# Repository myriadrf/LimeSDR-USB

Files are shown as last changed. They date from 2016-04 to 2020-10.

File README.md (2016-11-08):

# LimeSDR

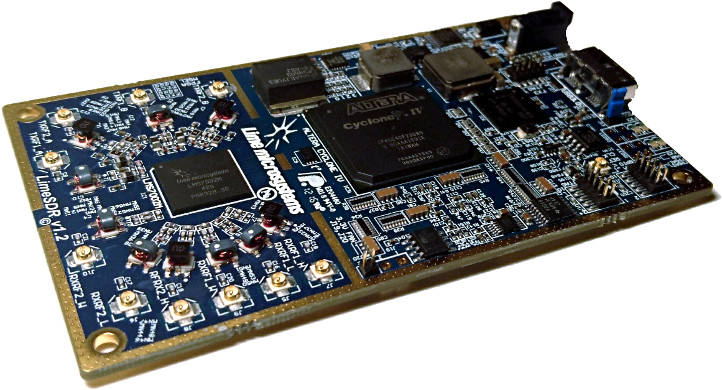
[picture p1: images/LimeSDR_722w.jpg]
LimeSDR board


The [LimeSDR](https://myriadrf.org/projects/limesdr/) board provides a hardware platform for developing and prototyping high-performance and logic-intensive digital and RF designs using Altera’s Cyclone IV FPGA and Lime Microsystems transceiver.

* **USB Interface** 
  * Cypress FX3 super speed USB 3rd generation controller 
* **FPGA Features**
  * Cyclone IV EP4CE40F23C8N device in 484-pin FPGA
  * 39’600 logic elements
  * 1134 Kbits embedded memory
  * 116 embedded 18x18 multipliers 
  * 4 PLLs 
* **FPGA Configuration**
  * JTAG mode configuration 
  * Active serial mode configuration 
  * Possibility to update FPGA gateware by using FX3 (USB)
* **Memory Devices** 
  * 2x 1Gbit (64M x 16) DDR2 SDRAM 
  * 4Mbit flash for FX3 firmware
  * 16Mbit flash for FPGA gateware
  * 3x 64K (8K x 8) EEPROMs for LMS MCU firmware, LMS MCU data and FX3 data
* **Connections**
  * 6-12V DC power jack
  * FPGA GPIO headers
  * Micro USB3.0 (type B) connector or USB3.0 (type A) plug
  * Coaxial RF (U.FL) connectors
* **Clock System**
  * 30.72MHz ±250 ppb on board VCTCXO
  * Possibility to lock VCTCXO to external clock or tune VCTCXO by onboard DAC 
  * Programmable clock generator for the FPGA reference clock input or LMS PLLs
* **Board Size** 60mm x 100mm (2.36” x 3.94”) 

## Contents

The directory structure is as follows:

      fx3/                       - Cypress FX3 USB 3.0 controller firmware
         
      gateware/                  - Altera Cyclone IV FPGA project

      hardware/<variant>/<version>/
          Libraries/             - Component Libraries
          OutputJobs/            - Output jobs
          PCB/                   - PCB design
          Project Outputs/       - BOM, rule check reports, Gerbers, pick & place files, PDFs
          Schematics/            - Schematic diagrams

### Revisions

The design databases published correspond to hardware revisions which have either gone into full production or been issued in limited number for testing in the community. 

Please note that only certain versions of FPGA firmware and FX3 firmware will work with a given hardware revision. For further details see the FPGA and FX3 projects.

## Associated projects

### FPGA gateware

The FPGA gateware sources are located in the [LimeSDR-USB_GW repository](https://github.com/myriadrf/LimeSDR-USB_GW).

### FX3 firmware

The Cypress FX3 USB 3.0 controller firmware sources are located in the [LimeSDR-USB_FX3 repository](https://github.com/myriadrf/LimeSDR-USB_FX3).

### Host driver

The host driver sources are located in the [LimeSuite repository](https://github.com/myriadrf/LimeSuite).

## Licensing

The hardware designs are licensed under a Creative Commons Attribution 3.0 Unported licence.

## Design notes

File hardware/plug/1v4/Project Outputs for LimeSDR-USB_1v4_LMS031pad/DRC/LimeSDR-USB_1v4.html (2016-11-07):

Altium

# Design Rule Verification Report

Date: | | 2016-09-13
Time: | | 16:37:09
Elapsed Time: | | 00:03:49
Filename: | | E:\Saniok\Lime Micro\Lime PCBs\LimeSDR-USB_1v4\Altium designer design files\PCB\LimeSDR-USB_1v4.PcbDoc

Warnings: | | 12
Rule Violations: | | 0

## Summary

Warnings | Count
Unplated multi-layer pad(s) detected | 12
Total | 12

Rule Violations | Count
Component Clearance Constraint ( Horizontal Gap = -2mm, Vertical Gap = Infinite ) (InComponent('J13')),(InComponent('J14')) | 0
Component Clearance Constraint ( Horizontal Gap = -2mm, Vertical Gap = Infinite ) (InComponent('J17')),(All) | 0
Differential Pairs Uncoupled Length using the Gap Constraints (Min=0.1mm) (Max=0.2mm) (Prefered=0.1mm) and Width Constraints (Min=0.1mm) (Max=0.4mm) (Prefered=0.1mm) (InNet('FX3_XTAL_N') or InNet('FX3_XTAL_P')) | 0
Matched Lengths(Tolerance=0.5mm) (InNetClass('DDR2_1_A[0..12]')) | 0
Matched Lengths(Tolerance=0.5mm) (InNetClass('DDR2_1_DQ[0..15]')) | 0
Matched Lengths(Tolerance=0.5mm) (InNetClass('DDR2_2_A[0..12]')) | 0
Matched Lengths(Tolerance=0.5mm) (InNetClass('DDR2_2_DQ[0..15]')) | 0
Net Antennae (Tolerance=0mm) (All) | 0
Hole To Hole Clearance (Gap=0.15mm) (All),(All) | 0
Routing Layers(All) | 0
Clearance Constraint (Gap=0.1mm) (All),(All) | 0
Short-Circuit Constraint (Allowed=No) (All),(All) | 0
Un-Routed Net Constraint ( (All) ) | 0
Power Plane Connect Rule(Relief Connect )(Expansion=0.508mm) (Conductor Width=0.254mm) (Air Gap=0.254mm) (Entries=4) (All) | 0
Width Constraint (Min=0.1mm) (Max=5mm) (Preferred=0.2mm) (All) | 0
Routing Via (MinHoleWidth=0.2mm) (MaxHoleWidth=4.5mm) (PreferredHoleWidth=0.2mm) (MinWidth=0.31mm) (MaxWidth=5mm) (PreferedWidth=0.4mm) (All) | 0
Pads and Vias to follow the Drill pairs settings | 0
Hole Size Constraint (Min=0.2mm) (Max=10mm) (All) | 0
Height Constraint (Min=0mm) (Max=14.47mm) (Prefered=14.47mm) (OnTopLayer) | 0
Differential Pairs Uncoupled Length using the Gap Constraints (Min=0.1mm) (Max=0.3mm) (Prefered=0.1mm) and Width Constraints (Min=0.1mm) (Max=0.5mm) (Prefered=0.2mm) (All) | 0
Component Clearance Constraint ( Horizontal Gap = 0.01mm, Vertical Gap = 0.254mm ) (All),(All) | 0
Height Constraint (Min=0mm) (Max=2.67mm) (Prefered=2.67mm) (OnBottomLayer) | 0
Modified Polygon (Allow modified: No), (Allow shelved: No) | 0
Differential Pairs Uncoupled Length using the Gap Constraints (Min=0.1mm) (Max=0.2mm) (Prefered=0.1mm) and Width Constraints (Min=0.1mm) (Max=0.4mm) (Prefered=0.1mm) (InNetClass('DDR2_1_CK') or InNetClass('DDR2_1_CK')) | 0
Matched Lengths(Tolerance=1mm) (InNetClass('LMS_PORT1')) | 0
Matched Lengths(Tolerance=1mm) (InNetClass('LMS_PORT2')) | 0
Differential Pairs Uncoupled Length using the Gap Constraints (Min=0.1mm) (Max=0.3mm) (Prefered=0.1mm) and Width Constraints (Min=0.2mm) (Max=0.2mm) (Prefered=0.2mm) (InNetClass('FX3_DATA')) | 0
Differential Pairs Uncoupled Length using the Gap Constraints (Min=0.1mm) (Max=0.3mm) (Prefered=0.2mm) and Width Constraints (Min=0.1mm) (Max=0.3mm) (Prefered=0.2mm) (InNetClass('TX_RF')) | 0
Differential Pairs Uncoupled Length using the Gap Constraints (Min=0.1mm) (Max=0.3mm) (Prefered=0.2mm) and Width Constraints (Min=0.1mm) (Max=0.3mm) (Prefered=0.2mm) (InNetClass('RX_RF')) | 0
Width Constraint (Min=0.1mm) (Max=7mm) (Preferred=0.2mm) (All) | 0
Component Clearance Constraint ( Horizontal Gap = -1mm, Vertical Gap = Infinite ) (InComponent('LEDS1') or InComponent('LEDS2') or InComponent('LED1') or InComponent('LED4') or InComponent('LED5') or InComponent('LED8')),(InComponent('LED1') or InComponent('LED4') or InComponent('LED5') or InComponent('LED8') or InComponent('LEDS1') or InComponent('LEDS2')) | 0
Total | 0

## Warnings

Unplated multi-layer pad(s) detected

Pad Free-2(78.5mm,60.1mm) on MultiLayer on Net GND

Pad Free-3(79.7mm,60.1mm) on MultiLayer on Net GND

Pad Free-4(80.875mm,60.1mm) on MultiLayer on Net GND

Pad Free-4(80.875mm,-0.1mm) on MultiLayer on Net GND

Pad Free-3(79.7mm,-0.1mm) on MultiLayer on Net GND

Pad Free-2(78.5mm,-0.1mm) on MultiLayer on Net GND

Pad Free-2(21.5mm,-0.1mm) on MultiLayer on Net GND

Pad Free-3(20.3mm,-0.1mm) on MultiLayer on Net GND

Pad Free-4(19.125mm,-0.1mm) on MultiLayer on Net GND

Pad Free-2(21.5mm,60.1mm) on MultiLayer on Net GND

Pad Free-3(20.3mm,60.1mm) on MultiLayer on Net GND

Pad Free-4(19.125mm,60.1mm) on MultiLayer on Net GND

Back to top

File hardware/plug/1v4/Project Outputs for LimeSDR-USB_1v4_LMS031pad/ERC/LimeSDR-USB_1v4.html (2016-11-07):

Altium

# Electrical Rule Check Report

Date: | | 2016-09-13
Time: | | 16:41:00
Filename: | | E:\Saniok\Lime Micro\Lime PCBs\LimeSDR-USB_1v4\Altium designer design files\Project Outputs for LimeSDR-USB_1v4\ERC\LimeSDR-USB_1v4.html

Class | Document | Message
Warning | 15_BoardPowerSupply.SchDoc | FPGA_LED1_R contains IO Pin and Power Pin objects (Pin LED1-3,Pin IC8-E3,Pin LEDS1-K1)
Warning | 15_BoardPowerSupply.SchDoc | FPGA_LED2_R contains IO Pin and Power Pin objects (Pin LED7-3,Pin IC8-E1,Pin LEDS1-K2)
Warning | 15_BoardPowerSupply.SchDoc | FX3_LED_R contains IO Pin and Power Pin objects (Pin LED2-3,Pin IC8-H5,Pin LEDS2-K1)

Warning

15_BoardPowerSupply.SchDoc

GND contains IO Pin and Power Pin objects (Pin LED8-3,Pin IC19-4,Pin IC22-5,Pin IC13-A1,Pin IC8-A1,Pin IC12-A3,Pin IC11-A3,Pin IC12-A7,Pin IC11-A7,Pin IC13-A8,Pin IC8-A19,Pin IC8-A22,Pin IC8-AA2,Pin IC8-AA22,Pin IC8-AB1,Pin IC8-AB6,Pin IC8-AB22,Pin IC12-B2,Pin IC11-B2,Pin IC8-B5,Pin IC13-B7,Pin IC13-B8,Pin IC12-B8,Pin IC11-B8,Pin IC13-B9,Pin IC8-B19,Pin IC8-C5,Pin IC8-C9,Pin IC8-C10,Pin IC8-C11,Pin IC8-C12,Pin IC8-C14,Pin IC8-C15,Pin IC8-C16,Pin IC8-C18,Pin IC12-D2,Pin IC11-D2,Pin IC8-D3,Pin IC8-D6,Pin IC13-D8,Pin IC12-D8,Pin IC11-D8,Pin IC8-D8,Pin IC8-D15,Pin IC8-D17,Pin IC8-D20,Pin IC13-E2,Pin IC12-E3,Pin IC11-E3,Pin IC12-E7,Pin IC11-E7,Pin IC8-E9,Pin IC8-E13,Pin IC8-E18,Pin IC8-E20,Pin IC12-F2,Pin IC11-F2,Pin IC8-F3,Pin IC8-F5,Pin IC12-F8,Pin IC11-F8,Pin IC8-F12,Pin IC8-F19,Pin IC8-F20,Pin IC13-G1,Pin IC8-G2,Pin IC13-G11,Pin IC8-G20,Pin IC12-H2,Pin IC11-H2,Pin IC8-H3,Pin IC12-H8,Pin IC11-H8,Pin IC8-H12,Pin IC8-H13,Pin IC8-H17,Pin IC8-H18,Pin IC12-J3,Pin IC11-J3,Pin IC12-J7,Pin IC11-J7,Pin IC8-J9,Pin IC8-J15,Pin IC8-J18,Pin IC8-J19,Pin LEDS2-K2,Pin IC13-K3,Pin IC8-K3,Pin IC13-K4,Pin IC8-K10,Pin IC8-K11,Pin IC8-K12,Pin IC8-K13,Pin IC8-K16,Pin IC8-K19,Pin IC13-L1,Pin IC13-L2,Pin IC13-L3,Pin IC13-L6,Pin IC8-L10,Pin IC13-L11,Pin IC8-L11,Pin IC8-L12,Pin IC8-L13,Pin IC8-L15,Pin IC8-L20,Pin IC8-M10,Pin IC8-M11,Pin IC8-M12,Pin IC8-M13,Pin IC8-M16,Pin IC12-N1,Pin IC11-N1,Pin IC8-N3,Pin IC8-N10,Pin IC8-N11,Pin IC8-N12,Pin IC8-N13,Pin IC8-N15,Pin IC8-P8,Pin IC12-P9,Pin IC11-P9,Pin IC8-P19,Pin IC8-P20,Pin IC8-R3,Pin IC8-R9,Pin IC8-R11,Pin IC8-R13,Pin IC8-R17,Pin IC8-T17,Pin IC8-T20,Pin IC8-U3,Pin IC8-U5,Pin IC8-V18,Pin IC8-V20,Pin IC8-W3,Pin IC8-W19,Pin IC8-Y5,Pin IC8-Y9,Pin IC8-Y11,Pin IC8-Y12,Pin IC8-Y15,Pin IC8-Y16,Pin IC8-Y18,Pin IC8-Y20)
Warning | 10_FPGA_misc.SchDoc | Net FPGA_JTAG_TCK has no driving source (Pin IC8-L2,Pin J11-1,Pin R62-1)
Warning | 10_FPGA_misc.SchDoc | Net FPGA_JTAG_TDI has no driving source (Pin IC8-L5,Pin J11-9,Pin R58-1)
Warning | 10_FPGA_misc.SchDoc | Net FPGA_JTAG_TMS has no driving source (Pin IC8-L1,Pin J11-5,Pin R55-1)
Warning | 12_USB3_0_device.SchDoc | Net FPGA_NCONFIG has no driving source (Pin IC8-K5,Pin R105-2,Pin R106-2)
Warning | 12_USB3_0_device.SchDoc | Net FX3_FSLC0 has no driving source (Pin IC13-B2,Pin R125-2)
Warning | 12_USB3_0_device.SchDoc | Net FX3_FSLC1 has no driving source (Pin IC13-B4,Pin R127-2)
Warning | 12_USB3_0_device.SchDoc | Net FX3_FSLC2 has no driving source (Pin IC13-E6,Pin R128-2)
Warning | 12_USB3_0_device.SchDoc | Net FX3_JTAG_TCK has no driving source (Pin IC13-F6,Pin J16-4)
Warning | 12_USB3_0_device.SchDoc | Net FX3_JTAG_TDI has no driving source (Pin IC13-E7,Pin J16-8)
Warning | 12_USB3_0_device.SchDoc | Net FX3_JTAG_TMS has no driving source (Pin IC13-E8,Pin J16-2)
Warning | 12_USB3_0_device.SchDoc | Net FX3_JTAG_TRST has no driving source (Pin IC13-B11,Pin R124-1)
Warning | 12_USB3_0_device.SchDoc | Net FX3_OTG_ID has no driving source (Pin IC13-C9,Pin J15-4,Pin R92-2)
Warning | 12_USB3_0_device.SchDoc | Net FX3_PCLK has no driving source (Pin IC8-T21,Pin R98-1)
Warning | 12_USB3_0_device.SchDoc | Net FX3_RST has no driving source (Pin C278-1,Pin IC13-C5,Pin R118-1,Pin R120-2,Pin SW1-2)
Warning | 12_USB3_0_device.SchDoc | Net FX3_USB_SSRX_N has no driving source (Pin IC13-A4,Pin IC14-4,Pin IC14-7,Pin J15-9)
Warning | 12_USB3_0_device.SchDoc | Net FX3_USB_SSRX_P has no driving source (Pin IC13-A3,Pin IC14-5,Pin IC14-6,Pin J15-10)
Warning | 14_Clocks.SchDoc | Net LMK_CLK has no driving source (Pin IC8-B12,Pin IC20-15)
Warning | 04_LMS7002M_Misc.SchDoc | Net LMS_MCLK1 has no driving source (Pin IC1-AB34,Pin IC8-G21)
Warning | 10_FPGA_misc.SchDoc | Net LMS_MCLK2 has no driving source (Pin IC1-P34,Pin IC8-B11)
Warning | 10_FPGA_misc.SchDoc | Net MSEL0 has no driving source (Pin IC8-M17,Pin R51-1,Pin R52-2)
Warning | 10_FPGA_misc.SchDoc | Net MSEL1 has no driving source (Pin IC8-L18,Pin R53-1,Pin R54-2)
Warning | 10_FPGA_misc.SchDoc | Net MSEL2 has no driving source (Pin IC8-L17,Pin R56-1,Pin R57-2)
Warning | 10_FPGA_misc.SchDoc | Net MSEL3 has no driving source (Pin IC8-K20,Pin R59-1,Pin R60-2)
Warning | 05_LMS7002M_RF1.SchDoc | Net NetC10_1 has no driving source (Pin C10-1,Pin IC4-5)
Warning | 05_LMS7002M_RF1.SchDoc | Net NetC19_1 has no driving source (Pin C19-1,Pin IC5-5)
Warning | 06_LMS7002M_RF2.SchDoc | Net NetC30_1 has no driving source (Pin C30-1,Pin IC6-5)
Warning | 06_LMS7002M_RF2.SchDoc | Net NetC39_1 has no driving source (Pin C39-1,Pin IC7-5)
Warning | 15_BoardPowerSupply.SchDoc | Net NetC383_2 has no driving source (Pin C383-2,Pin FR58-2,Pin IC28-5,Pin IC28-8)
Warning | 15_BoardPowerSupply.SchDoc | Net NetC397_2 has no driving source (Pin C397-2,Pin FR59-2,Pin IC30-5,Pin IC30-8)
Warning | 15_BoardPowerSupply.SchDoc | Net NetC404_2 has no driving source (Pin C404-2,Pin FR60-2,Pin IC33-5,Pin IC33-8)
Warning | 15_BoardPowerSupply.SchDoc | Net NetC420_2 has no driving source (Pin C420-2,Pin FR62-2,Pin IC36-3)
Warning | 15_BoardPowerSupply.SchDoc | Net NetC421_2 has no driving source (Pin C421-2,Pin IC36-1,Pin R211-2,Pin R212-1)
Warning | 15_BoardPowerSupply.SchDoc | Net NetIC36_8 has no driving source (Pin IC36-8,Pin R209-2,Pin R210-2)
Warning | 14_Clocks.SchDoc | Net SI_CLK0 has no driving source (Pin IC8-T2,Pin IC24-13)
Warning | 14_Clocks.SchDoc | Net SI_CLK1 has no driving source (Pin IC8-AA12,Pin IC24-12)
Warning | 14_Clocks.SchDoc | Net SI_CLK2 has no driving source (Pin IC8-AB12,Pin IC24-9)
Warning | 14_Clocks.SchDoc | Net SI_CLK3 has no driving source (Pin IC8-T22,Pin IC24-8)
Warning | 14_Clocks.SchDoc | Net SI_CLK5 has no driving source (Pin IC8-G1,Pin IC24-17)
Warning | 14_Clocks.SchDoc | Net SI_CLK6 has no driving source (Pin IC8-AA11,Pin IC24-16)
Warning | 14_Clocks.SchDoc | Net SI_CLK7 has no driving source (Pin IC8-AB11,Pin IC24-15)

Back to top

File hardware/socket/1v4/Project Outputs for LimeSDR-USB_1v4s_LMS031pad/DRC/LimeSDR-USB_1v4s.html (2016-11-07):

Altium

# Design Rule Verification Report

Date: | | 2016-09-13
Time: | | 17:07:08
Elapsed Time: | | 00:03:37
Filename: | | E:\Saniok\Lime Micro\Lime PCBs\LimeSDR-USB_1v4s\Altium designer design files\PCB\LimeSDR-USB_1v4s.PcbDoc

Warnings: | | 12
Rule Violations: | | 0

## Summary

Warnings | Count
Unplated multi-layer pad(s) detected | 12
Total | 12

Rule Violations | Count
Component Clearance Constraint ( Horizontal Gap = -1mm, Vertical Gap = Infinite ) (InComponent('LEDS1') or InComponent('LEDS2') or InComponent('LED1') or InComponent('LED4') or InComponent('LED5') or InComponent('LED8')),(InComponent('LED1') or InComponent('LED4') or InComponent('LED5') or InComponent('LED8') or InComponent('LEDS1') or InComponent('LEDS2')) | 0
Width Constraint (Min=0.1mm) (Max=7mm) (Preferred=0.2mm) (All) | 0
Differential Pairs Uncoupled Length using the Gap Constraints (Min=0.1mm) (Max=0.3mm) (Prefered=0.2mm) and Width Constraints (Min=0.1mm) (Max=0.3mm) (Prefered=0.2mm) (InNetClass('RX_RF')) | 0
Differential Pairs Uncoupled Length using the Gap Constraints (Min=0.1mm) (Max=0.3mm) (Prefered=0.2mm) and Width Constraints (Min=0.1mm) (Max=0.3mm) (Prefered=0.2mm) (InNetClass('TX_RF')) | 0
Differential Pairs Uncoupled Length using the Gap Constraints (Min=0.1mm) (Max=0.3mm) (Prefered=0.1mm) and Width Constraints (Min=0.2mm) (Max=0.2mm) (Prefered=0.2mm) (InNetClass('FX3_DATA')) | 0
Matched Lengths(Tolerance=1mm) (InNetClass('LMS_PORT2')) | 0
Matched Lengths(Tolerance=1mm) (InNetClass('LMS_PORT1')) | 0
Differential Pairs Uncoupled Length using the Gap Constraints (Min=0.1mm) (Max=0.2mm) (Prefered=0.1mm) and Width Constraints (Min=0.1mm) (Max=0.4mm) (Prefered=0.1mm) (InNetClass('DDR2_1_CK') or InNetClass('DDR2_1_CK')) | 0
Modified Polygon (Allow modified: No), (Allow shelved: No) | 0
Height Constraint (Min=0mm) (Max=2.67mm) (Prefered=2.67mm) (OnBottomLayer) | 0
Component Clearance Constraint ( Horizontal Gap = 0.01mm, Vertical Gap = 0.254mm ) (All),(All) | 0
Differential Pairs Uncoupled Length using the Gap Constraints (Min=0.1mm) (Max=0.3mm) (Prefered=0.1mm) and Width Constraints (Min=0.1mm) (Max=0.5mm) (Prefered=0.2mm) (All) | 0
Height Constraint (Min=0mm) (Max=14.47mm) (Prefered=14.47mm) (OnTopLayer) | 0
Hole Size Constraint (Min=0.2mm) (Max=10mm) (All) | 0
Pads and Vias to follow the Drill pairs settings | 0
Routing Via (MinHoleWidth=0.2mm) (MaxHoleWidth=4.5mm) (PreferredHoleWidth=0.2mm) (MinWidth=0.31mm) (MaxWidth=5mm) (PreferedWidth=0.4mm) (All) | 0
Width Constraint (Min=0.1mm) (Max=5mm) (Preferred=0.2mm) (All) | 0
Power Plane Connect Rule(Relief Connect )(Expansion=0.508mm) (Conductor Width=0.254mm) (Air Gap=0.254mm) (Entries=4) (All) | 0
Un-Routed Net Constraint ( (All) ) | 0
Short-Circuit Constraint (Allowed=No) (All),(All) | 0
Clearance Constraint (Gap=0.1mm) (All),(All) | 0
Routing Layers(All) | 0
Hole To Hole Clearance (Gap=0.15mm) (All),(All) | 0
Net Antennae (Tolerance=0mm) (All) | 0
Matched Lengths(Tolerance=0.5mm) (InNetClass('DDR2_2_DQ[0..15]')) | 0
Matched Lengths(Tolerance=0.5mm) (InNetClass('DDR2_2_A[0..12]')) | 0
Matched Lengths(Tolerance=0.5mm) (InNetClass('DDR2_1_DQ[0..15]')) | 0
Matched Lengths(Tolerance=0.5mm) (InNetClass('DDR2_1_A[0..12]')) | 0
Differential Pairs Uncoupled Length using the Gap Constraints (Min=0.1mm) (Max=0.2mm) (Prefered=0.1mm) and Width Constraints (Min=0.1mm) (Max=0.4mm) (Prefered=0.1mm) (InNet('FX3_XTAL_N') or InNet('FX3_XTAL_P')) | 0
Component Clearance Constraint ( Horizontal Gap = -2mm, Vertical Gap = Infinite ) (InComponent('J17')),(All) | 0
Component Clearance Constraint ( Horizontal Gap = -2mm, Vertical Gap = Infinite ) (InComponent('J13')),(InComponent('J14')) | 0
Total | 0

## Warnings

Unplated multi-layer pad(s) detected

Pad Free-4(19.125mm,60.1mm) on MultiLayer on Net GND

Pad Free-3(20.3mm,60.1mm) on MultiLayer on Net GND

Pad Free-2(21.5mm,60.1mm) on MultiLayer on Net GND

Pad Free-4(19.125mm,-0.1mm) on MultiLayer on Net GND

Pad Free-3(20.3mm,-0.1mm) on MultiLayer on Net GND

Pad Free-2(21.5mm,-0.1mm) on MultiLayer on Net GND

Pad Free-2(78.5mm,-0.1mm) on MultiLayer on Net GND

Pad Free-3(79.7mm,-0.1mm) on MultiLayer on Net GND

Pad Free-4(80.875mm,-0.1mm) on MultiLayer on Net GND

Pad Free-4(80.875mm,60.1mm) on MultiLayer on Net GND

Pad Free-3(79.7mm,60.1mm) on MultiLayer on Net GND

Pad Free-2(78.5mm,60.1mm) on MultiLayer on Net GND

Back to top

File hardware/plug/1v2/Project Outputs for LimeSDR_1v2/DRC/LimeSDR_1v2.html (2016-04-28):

Altium

# Design Rule Verification Report

Date: | | 2016-03-11
Time: | | 16:50:42
Elapsed Time: | | 00:03:20
Filename: | | E:\Saniok\Lime Micro\Lime PCBs\LimeSDR_1v2\AltiumDesigner Design Files\PCB\LimeSDR_1v2.PcbDoc

Warnings: | | 12
Rule Violations: | | 0

## Summary

Warnings | Count
Unplated multi-layer pad(s) detected | 12
Total | 12

Rule Violations | Count
Component Clearance Constraint ( Horizontal Gap = -1mm, Vertical Gap = Infinite ) (InComponent('LEDS1') or InComponent('LEDS2') or InComponent('LED1') or InComponent('LED4') or InComponent('LED5') or InComponent('LED8')),(InComponent('LED1') or InComponent('LED4') or InComponent('LED5') or InComponent('LED8') or InComponent('LEDS1') or InComponent('LEDS2')) | 0
Width Constraint (Min=0.1mm) (Max=7mm) (Preferred=0.2mm) (All) | 0
Differential Pairs Uncoupled Length using the Gap Constraints (Min=0.1mm) (Max=0.3mm) (Prefered=0.2mm) and Width Constraints (Min=0.1mm) (Max=0.3mm) (Prefered=0.2mm) (InNetClass('RX_RF')) | 0
Differential Pairs Uncoupled Length using the Gap Constraints (Min=0.1mm) (Max=0.3mm) (Prefered=0.2mm) and Width Constraints (Min=0.1mm) (Max=0.3mm) (Prefered=0.2mm) (InNetClass('TX_RF')) | 0
Differential Pairs Uncoupled Length using the Gap Constraints (Min=0.1mm) (Max=0.3mm) (Prefered=0.1mm) and Width Constraints (Min=0.2mm) (Max=0.2mm) (Prefered=0.2mm) (InNetClass('FX3_DATA')) | 0
Matched Lengths(Tolerance=15mm) (InNetClass('LMS_PORT2')) | 0
Matched Lengths(Tolerance=15mm) (InNetClass('LMS_PORT1')) | 0
Differential Pairs Uncoupled Length using the Gap Constraints (Min=0.1mm) (Max=0.2mm) (Prefered=0.1mm) and Width Constraints (Min=0.1mm) (Max=0.4mm) (Prefered=0.1mm) (InNetClass('DDR2_1_CK') or InNetClass('DDR2_1_CK')) | 0
Modified Polygon (Allow modified: No), (Allow shelved: No) | 0
Height Constraint (Min=0mm) (Max=2.67mm) (Prefered=2.67mm) (OnBottomLayer) | 0
Component Clearance Constraint ( Horizontal Gap = 0.01mm, Vertical Gap = 0.254mm ) (All),(All) | 0
Differential Pairs Uncoupled Length using the Gap Constraints (Min=0.1mm) (Max=0.3mm) (Prefered=0.1mm) and Width Constraints (Min=0.1mm) (Max=0.5mm) (Prefered=0.2mm) (All) | 0
Height Constraint (Min=0mm) (Max=14.47mm) (Prefered=14.47mm) (OnTopLayer) | 0
Hole Size Constraint (Min=0.2mm) (Max=10mm) (All) | 0
Pads and Vias to follow the Drill pairs settings | 0
Routing Via (MinHoleWidth=0.2mm) (MaxHoleWidth=4.5mm) (PreferredHoleWidth=0.2mm) (MinWidth=0.35mm) (MaxWidth=5mm) (PreferedWidth=0.4mm) (All) | 0
Width Constraint (Min=0.1mm) (Max=5mm) (Preferred=0.2mm) (All) | 0
Power Plane Connect Rule(Relief Connect )(Expansion=0.508mm) (Conductor Width=0.254mm) (Air Gap=0.254mm) (Entries=4) (All) | 0
Un-Routed Net Constraint ( (All) ) | 0
Short-Circuit Constraint (Allowed=No) (All),(All) | 0
Clearance Constraint (Gap=0.1mm) (All),(All) | 0
Routing Layers(All) | 0
Hole To Hole Clearance (Gap=0.15mm) (All),(All) | 0
Net Antennae (Tolerance=0mm) (All) | 0
Matched Lengths(Tolerance=0.5mm) (InNetClass('DDR2_2_DQ[0..15]')) | 0
Matched Lengths(Tolerance=0.5mm) (InNetClass('DDR2_2_A[0..12]')) | 0
Matched Lengths(Tolerance=0.5mm) (InNetClass('DDR2_1_DQ[0..15]')) | 0
Matched Lengths(Tolerance=0.5mm) (InNetClass('DDR2_1_A[0..12]')) | 0
Differential Pairs Uncoupled Length using the Gap Constraints (Min=0.1mm) (Max=0.2mm) (Prefered=0.1mm) and Width Constraints (Min=0.1mm) (Max=0.4mm) (Prefered=0.1mm) (InNet('FX3_XTAL_N') or InNet('FX3_XTAL_P')) | 0
Component Clearance Constraint ( Horizontal Gap = -1mm, Vertical Gap = Infinite ) (InComponent('J13')),(InComponent('JMP1')) | 0
Component Clearance Constraint ( Horizontal Gap = -1mm, Vertical Gap = Infinite ) (InComponent('J19')),(InComponent('J20')) | 0
Total | 0

## Warnings

Unplated multi-layer pad(s) detected

Pad Free-4(19.125mm,60.1mm) on MultiLayer on Net GND

Pad Free-3(20.3mm,60.1mm) on MultiLayer on Net GND

Pad Free-2(21.5mm,60.1mm) on MultiLayer on Net GND

Pad Free-4(19.125mm,-0.1mm) on MultiLayer on Net GND

Pad Free-3(20.3mm,-0.1mm) on MultiLayer on Net GND

Pad Free-2(21.5mm,-0.1mm) on MultiLayer on Net GND

Pad Free-2(78.5mm,-0.1mm) on MultiLayer on Net GND

Pad Free-3(79.7mm,-0.1mm) on MultiLayer on Net GND

Pad Free-4(80.875mm,-0.1mm) on MultiLayer on Net GND

Pad Free-4(80.875mm,60.1mm) on MultiLayer on Net GND

Pad Free-3(79.7mm,60.1mm) on MultiLayer on Net GND

Pad Free-2(78.5mm,60.1mm) on MultiLayer on Net GND

Back to top

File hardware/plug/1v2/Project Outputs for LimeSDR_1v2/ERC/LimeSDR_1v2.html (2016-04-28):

Altium

# Electrical Rule Check Report

Date: | | 2016-03-11
Time: | | 16:54:05
Filename: | | E:\Saniok\Lime Micro\Lime PCBs\LimeSDR_1v2\AltiumDesigner Design Files\Project Outputs for LimeSDR_1v2\ERC\LimeSDR_1v2.html

Class | Document | Message
Warning | 14_BoardPowerSupply.SchDoc | FPGA_LED1_R contains IO Pin and Power Pin objects (Pin LED1-3,Pin IC31-E3,Pin LEDS1-K1)
Warning | 14_BoardPowerSupply.SchDoc | FPGA_LED2_R contains IO Pin and Power Pin objects (Pin LED4-3,Pin IC31-E1,Pin LEDS1-K2)

Warning

14_BoardPowerSupply.SchDoc

GND contains IO Pin and Power Pin objects (Pin LED8-3,Pin IC12-4,Pin IC15-5,Pin IC6-A1,Pin IC31-A1,Pin IC5-A3,Pin IC4-A3,Pin IC5-A7,Pin IC4-A7,Pin IC6-A8,Pin IC31-A19,Pin IC31-A22,Pin IC31-AA2,Pin IC31-AA22,Pin IC31-AB1,Pin IC31-AB6,Pin IC31-AB22,Pin IC5-B2,Pin IC4-B2,Pin IC31-B5,Pin IC6-B7,Pin IC6-B8,Pin IC5-B8,Pin IC4-B8,Pin IC6-B9,Pin IC31-B19,Pin IC31-C5,Pin IC31-C9,Pin IC31-C10,Pin IC31-C11,Pin IC31-C12,Pin IC31-C14,Pin IC31-C15,Pin IC31-C16,Pin IC31-C18,Pin IC5-D2,Pin IC4-D2,Pin IC31-D3,Pin IC31-D6,Pin IC6-D8,Pin IC5-D8,Pin IC4-D8,Pin IC31-D8,Pin IC31-D15,Pin IC31-D17,Pin IC31-D20,Pin IC6-E2,Pin IC5-E3,Pin IC4-E3,Pin IC5-E7,Pin IC4-E7,Pin IC31-E9,Pin IC31-E13,Pin IC31-E18,Pin IC31-E20,Pin IC5-F2,Pin IC4-F2,Pin IC31-F3,Pin IC31-F5,Pin IC5-F8,Pin IC4-F8,Pin IC31-F12,Pin IC6-G1,Pin IC31-G2,Pin IC31-G5,Pin IC6-G11,Pin IC31-G20,Pin IC5-H2,Pin IC4-H2,Pin IC31-H3,Pin IC31-H5,Pin IC5-H8,Pin IC4-H8,Pin IC31-H12,Pin IC31-H13,Pin IC31-H18,Pin IC5-J3,Pin IC4-J3,Pin IC5-J7,Pin IC4-J7,Pin IC31-J9,Pin IC31-J15,Pin IC31-J18,Pin IC31-J19,Pin LEDS2-K2,Pin IC6-K3,Pin IC31-K3,Pin IC6-K4,Pin IC31-K10,Pin IC31-K11,Pin IC31-K12,Pin IC31-K13,Pin IC31-K16,Pin IC31-K19,Pin IC6-L1,Pin IC6-L2,Pin IC6-L3,Pin IC6-L6,Pin IC31-L10,Pin IC6-L11,Pin IC31-L11,Pin IC31-L12,Pin IC31-L13,Pin IC31-L15,Pin IC31-L20,Pin IC31-M10,Pin IC31-M11,Pin IC31-M12,Pin IC31-M13,Pin IC31-M16,Pin IC5-N1,Pin IC4-N1,Pin IC31-N3,Pin IC31-N10,Pin IC31-N11,Pin IC31-N12,Pin IC31-N13,Pin IC31-N15,Pin IC31-P8,Pin IC5-P9,Pin IC4-P9,Pin IC31-P19,Pin IC31-P20,Pin IC31-R3,Pin IC31-R9,Pin IC31-R11,Pin IC31-R13,Pin IC31-R17,Pin IC31-T17,Pin IC31-T20,Pin IC31-U3,Pin IC31-U5,Pin IC31-V18,Pin IC31-V20,Pin IC31-W3,Pin IC31-W19,Pin IC31-Y5,Pin IC31-Y9,Pin IC31-Y11,Pin IC31-Y12,Pin IC31-Y15,Pin IC31-Y16,Pin IC31-Y18,Pin IC31-Y20)
Warning | 11_USB3_0_device.SchDoc | Net FPGA_NCONFIG has no driving source (Pin IC31-K5,Pin R66-2,Pin R67-2)
Warning | 11_USB3_0_device.SchDoc | Net FX3_FSLC0 has no driving source (Pin IC6-B2,Pin R83-2)
Warning | 11_USB3_0_device.SchDoc | Net FX3_FSLC1 has no driving source (Pin IC6-B4,Pin R86-2)
Warning | 11_USB3_0_device.SchDoc | Net FX3_FSLC2 has no driving source (Pin IC6-E6,Pin R87-2)
Warning | 11_USB3_0_device.SchDoc | Net FX3_JTAG_TCK has no driving source (Pin IC6-F6,Pin J12-4)
Warning | 11_USB3_0_device.SchDoc | Net FX3_JTAG_TDI has no driving source (Pin IC6-E7,Pin J12-8)
Warning | 11_USB3_0_device.SchDoc | Net FX3_JTAG_TMS has no driving source (Pin IC6-E8,Pin J12-2)
Warning | 11_USB3_0_device.SchDoc | Net FX3_JTAG_TRST has no driving source (Pin IC6-B11,Pin R84-1)
Warning | 11_USB3_0_device.SchDoc | Net FX3_OTG_ID has no driving source (Pin IC6-C9,Pin J11-4,Pin R53-2)
Warning | 11_USB3_0_device.SchDoc | Net FX3_RST has no driving source (Pin C138-1,Pin IC6-C5,Pin R78-1,Pin R80-2,Pin SW1-2)
Warning | 11_USB3_0_device.SchDoc | Net FX3_USB_SSRX_N has no driving source (Pin IC6-A4,Pin IC7-4,Pin IC7-7,Pin J11-9)
Warning | 11_USB3_0_device.SchDoc | Net FX3_USB_SSRX_P has no driving source (Pin IC6-A3,Pin IC7-5,Pin IC7-6,Pin J11-10)
Warning | 13_Clocks.SchDoc | Net LMK_CLK has no driving source (Pin IC13-15,Pin IC31-B12)
Warning | 04_LMS7002M_Digital.SchDoc | Net LMS_MCLK1 has no driving source (Pin IC1-AB34,Pin IC31-G21)
Warning | 09_FPGA_misc.SchDoc | Net LMS_MCLK2 has no driving source (Pin IC1-P34,Pin IC31-B11)
Warning | 09_FPGA_misc.SchDoc | Net MSEL0 has no driving source (Pin IC31-M17,Pin R168-1,Pin R169-2)
Warning | 09_FPGA_misc.SchDoc | Net MSEL1 has no driving source (Pin IC31-L18,Pin R170-1,Pin R171-2)
Warning | 09_FPGA_misc.SchDoc | Net MSEL2 has no driving source (Pin IC31-L17,Pin R174-1,Pin R175-2)
Warning | 09_FPGA_misc.SchDoc | Net MSEL3 has no driving source (Pin IC31-K20,Pin R178-1,Pin R179-2)
Warning | 13_Clocks.SchDoc | Net SI_CLK0 has no driving source (Pin IC17-13,Pin IC31-T2)
Warning | 13_Clocks.SchDoc | Net SI_CLK1 has no driving source (Pin IC17-12,Pin IC31-AA12)
Warning | 13_Clocks.SchDoc | Net SI_CLK2 has no driving source (Pin IC17-9,Pin IC31-T21)
Warning | 13_Clocks.SchDoc | Net SI_CLK3 has no driving source (Pin IC17-8,Pin IC31-T22)
Warning | 13_Clocks.SchDoc | Net SI_CLK5 has no driving source (Pin IC17-17,Pin IC31-G1)
Warning | 13_Clocks.SchDoc | Net SI_CLK6 has no driving source (Pin IC17-16,Pin IC31-AA11)
Warning | 13_Clocks.SchDoc | Net SI_CLK7 has no driving source (Pin IC17-15,Pin IC31-AB11)

Back to top

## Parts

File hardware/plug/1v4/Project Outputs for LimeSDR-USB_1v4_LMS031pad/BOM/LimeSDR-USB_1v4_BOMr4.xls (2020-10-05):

Item # | Comment | Quantity | Designator | Footprint | Manufacturer | Manufacturer Part Number 1 | Supplier 1 | Supplier Part Number 1 | Part Description | Assembly Info
1 | 10pF, 25V | 4 | C1, C361, C362, C363 | CAP0402 | AVX | 04023A100JAT2A | Farnell | 2332478RL | 10pF ±5% 25V C0G, NP0 Ceramic Capacitor -55°C ~ 125°C Surface Mount, MLCC 0402 (1005 Metric) 0.039" L x 0.020" W (1.00mm x 0.50mm)
2 | 1uF, 10V | 22 | C2, C3, C118, C123, C130, C135, C140, C145, C242, C267, C326, C329, C333, C334, C341, C380, C382, C388, C394, C396, C403, C408 | CAP0402 | TDK | GRM155R61A105KE15J | Newark | 490-6298-2-ND | 1µF ±10% 10V X5R Ceramic Capacitor -55°C ~ 85°C Surface Mount, MLCC 0402 (1005 Metric) 0.039" L x 0.020" W (1.00mm x 0.50mm) | NF(C341)
3 | 100nF, 16V | 193 | C4, C5, C6, C7, C8, C24, C25, C26, C27, C28, C103, C104, C105, C106, C107, C108, C109, C110, C111, C112, C113, C114, C119, C124, C125, C131, C136, C141, C146, C147, C148, C149, C150, C151, C152, C153, C154, C155, C156, C157, C158, C159, C160, C161, C162, C163, C164, C165, C166, C167, C168, C169, C170, C171, C172, C173, C174, C175, C176, C177, C178, C179, C180, C181, C182, C183, C184, C185, C186, C187, C188, C189, C190, C191, C192, C193, C194, C195, C196, C197, C198, C199, C200, C201, C202, C203, C204, C205, C206, C207, C208, C209, C210, C211, C212, C213, C214, C215, C216, C217, C218, C219, C220, C221, C222, C223, C224, C226, C227, C228, C229, C232, C233, C234, C235, C236, C237, C238, C239, C243, C244, C246, C247, C248, C249, C251, C252, C253, C254, C257, C258, C259, C260, C261, C262, C263, C264, C268, C269, C270, C271, C272, C274, C276, C278, C279, C280, C281, C282, C284, C285, C288, C291, C293, C296, C299, C300, C302, C305, C306, C307, C308, C309, C310, C311, C312, C321, C322, C323, C327, C328, C330, C335, C338, C342, C345, C346, C352, C359, C360, C364, C365, C366, C372, C373, C378, C381, C395, C399, MN5, MN8, MN33, MN36 | CAP0402 | Murata Electronics | GRM155R71C104KA88D | Mouser | 81-GRM155R71C104KA88 | 0.10µF ±10% 16V X7R Ceramic Capacitor -55°C ~ 125°C Surface Mount, MLCC 0402 (1005 Metric) 0.039" L x 0.020" W (1.00mm x 0.50mm)
4 | 100pF, 50V | 35 | C9, C10, C13, C15, C16, C17, C18, C19, C20, C29, C30, C33, C35, C36, C37, C38, C39, C40, C331, C332, C336, C337, C339, C340, C343, C344, C347, C348, C349, C350, C351, MN25, MN28, MN53, MN56 | CAP0402 | Yageo | CC0402JRNPO9BN101 | Digi-Key | 311-1024-1-ND | 100pF ±5% 50V C0G, NP0 Ceramic Capacitor -55°C ~ 125°C Surface Mount, MLCC 0402 (1005 Metric) 0.039" L x 0.020" W (1.00mm x 0.50mm)
5 | 47pF | 10 | C11, C12, C21, C22, C31, C32, C41, C42, C324, C325 | CAP0402 | TDK Corporation | C1005C0G1H470F050BA | Digi-Key | 445-5361-1-ND | 47pF ±1% 50V C0G, NP0 Ceramic Capacitor -55°C ~ 125°C Surface Mount, MLCC 0402 (1005 Metric) 0.039" L x 0.020" W (1.00mm x 0.50mm) | NF(C324 C325)
6 | 470pF, 50V | 4 | C14, C23, C34, C43 | CAP0402 | TDK Corporation | C1005C0G1H471J050BA | Digi-Key | 445-2656-6-ND | 470pF ±5% 50V C0G, NP0 Ceramic Capacitor -55°C ~ 125°C Surface Mount, MLCC 0402 (1005 Metric) 0.039" L x 0.020" W (1.00mm x 0.50mm)
7 | 1uF, 20% | 50 | C44, C46, C48, C50, C52, C54, C56, C58, C60, C62, C63, C64, C65, C66, C67, C68, C69, C70, C71, C72, C73, C74, C75, C76, C77, C78, C79, C80, C81, C82, C83, C84, C85, C86, C87, C88, C89, C90, C91, C92, C93, C94, C95, C96, C97, C98, C99, C100, C101, C102 | CAP0201 | TDK Corporation | C0603X5R0J105M030BC | Digi-Key | 445-8008-1-ND | 1µF ±20% 6.3V X5R Ceramic Capacitor -55°C ~ 85°C Surface Mount, MLCC 0201 (0603 Metric) 0.024" L x 0.012" W (0.60mm x 0.30mm)
8 | 1nF, 10% | 9 | C45, C47, C49, C51, C53, C55, C57, C59, C61 | CAP0201 | TDK Corporation | C0603X7R1E102K030BA | Digi-Key | 445-7275-1-ND | 1000pF ±10% 25V X7R Ceramic Capacitor -55°C ~ 125°C Surface Mount, MLCC 0201 (0603 Metric) 0.024" L x 0.012" W (0.60mm x 0.30mm)
9 | 220uF, 4V | 6 | C115, C120, C126, C245, C406, C407 | CAP1206 | Murata Electronics North America | GRM31CR60G227ME11L | Digi-Key | 490-9774-1-ND | 220µF ±20% 4V X5R Ceramic Capacitor -55°C ~ 85°C Surface Mount, MLCC 1206 (3216 Metric) 0.126" L x 0.063" W (3.20mm x 1.60mm)
10 | 10uF, 6.3V | 14 | C116, C121, C128, C133, C138, C143, C240, C265, C295, C387, C392, C393, C415, C417 | CAP0603 | Yageo | CC0603MRX5R5BB106 | Digi-Key | 311-1448-2-ND | 10µF ±20% 6.3V X5R Ceramic Capacitor -55°C ~ 85°C Surface Mount, MLCC 0603 (1608 Metric) 0.063" L x 0.031" W (1.60mm x 0.80mm)
11 | 4.7uF, 6.3V | 22 | C117, C122, C129, C134, C139, C144, C241, C266, C376, C377, C383, C384, C397, C398, C401, C402, C404, C405, C409, C410, C414, C418 | CAP0402 | Murata Electronics North America | GRM155R60J475ME87D | Digi-Key | 490-5408-1-ND | 4.7µF ±20% 6.3V X5R Ceramic Capacitor -55°C ~ 85°C Surface Mount, MLCC 0402 (1005 Metric) 0.039" L x 0.020" W (1.00mm x 0.50mm)
12 | 100uF, 6.3V | 6 | C127, C132, C137, C142, C385, C386 | CAP1206 | Murata Electronics North America | GRM31CR60J107ME39L. | Farnell | 1735535 | 100µF ±20% 6.3V X5R Ceramic Capacitor -55°C ~ 85°C Surface Mount, MLCC 1206 (3216 Metric) 0.126" L x 0.063" W (3.20mm x 1.60mm) | NF(C142)
13 | 0.1uF | 6 | C225, C230, C231, C250, C255, C256 | CKCA43X7R1C104M100AA | TDK | CKCA43X7R1C104M100AA | Mouser | 810-CKCA43X7R1C104M | CAP ARRAY 0.1UF 16V X7R 1206
14 | 1uF, 16V | 1 | C273 | CAP0603 | Taiyo Yuden | EMK107B7105KA-T | Digi-Key | 587-1241-6-ND | 1µF ±10% 16V X7R Ceramic Capacitor -55°C ~ 125°C Surface Mount, MLCC 0603 (1608 Metric) 0.063" L x 0.031" W (1.60mm x 0.80mm)
15 | 13pF, 5% | 2 | C275, C277 | CAP0402 | Murata Electronics North America | GRM1555C1H130JA01D | Digi-Key | 490-5925-2-ND | 13pF ±5% 50V C0G, NP0 Ceramic Capacitor -55°C ~ 125°C Surface Mount, MLCC 0402 (1005 Metric) 0.039" L x 0.020" W (1.00mm x 0.50mm)
16 | 22uF, 10V | 6 | C283, C290, C298, C301, C303, C304 | CAP0603 | TDK | C1608X5R1A226M080AC | Mouser | 810-C1608X5R1A226M | 22µF ±20% 10V X5R Ceramic Capacitor -55°C ~ 85°C Surface Mount, MLCC 0603 (1608 Metric) 0.063" L x 0.031" W (1.60mm x 0.80mm)
17 | 10nF, 10% | 14 | C286, C287, C289, C292, C294, C297, C313, C314, C315, C316, C317, C318, C319, C320 | CAP0402 | Yageo | CC0402KRX7R9BB103 | Digi-Key | 311-1349-2-ND | 10000pF ±10% 50V X7R Ceramic Capacitor -55°C ~ 125°C Surface Mount, MLCC 0402 (1005 Metric) 0.039" L x 0.020" W (1.00mm x 0.50mm)
18 | 1nF, 10% | 2 | C353, C354 | CAP0402 | Murata Electronics | GCM155R71H102KA37D | Mouser | 81-GCM155R71H102KA7D | 1000pF ±10% 50V X7R Ceramic Capacitor -55°C ~ 125°C Surface Mount, MLCC 0402 (1005 Metric) 0.039" L x 0.020" W (1.00mm x 0.50mm)
19 | 22pF, 5% | 3 | C355, C356, C357 | CAP0402 | Yageo | CC0402JRNPO9BN220 | Digi-Key | 311-1018-2-ND | 22pF ±5% 50V C0G, NP0 Ceramic Capacitor -55°C ~ 125°C Surface Mount, MLCC 0402 (1005 Metric) 0.039" L x 0.020" W (1.00mm x 0.50mm)
20 | 220pF, 10% | 1 | C358 | CAP0402 | Yageo | CC0402KRX7R9BB221 | Digi-Key | 311-1035-2-ND | 220pF ±10% 50V X7R Ceramic Capacitor -55°C ~ 125°C Surface Mount, MLCC 0402 (1005 Metric) 0.039" L x 0.020" W (1.00mm x 0.50mm)
21 | 10uF, 25V | 11 | C367, C368, C369, C370, C371, C374, C379, C400, C419, C420, C421 | CAP0603 | Murata Electronics North America | GRM188R61E106MA73D | Digi-Key | 490-7202-2-ND | 10µF ±20% 25V X5R Ceramic Capacitor -55°C ~ 85°C Surface Mount, MLCC 0603 (1608 Metric) 0.063" L x 0.031" W (1.60mm x 0.80mm)
22 | 10uF, 16V | 2 | C375, C416 | CAP0603 | Yageo | GRM188R61C106MA73D | Digi-Key | 490-7201-2-ND | 10µF ±20% 16V X5R Ceramic Capacitor -55°C ~ 85°C Surface Mount, MLCC 0603 (1608 Metric) 0.063" L x 0.031" W (1.60mm x 0.80mm)
23 | 4.7pF, 50V | 1 | C389 | CAP0402 | Murata Electronics North America | GRM1555C1H4R7CA01D | Farnell | 2434644 | 4.7pF ±0.25pF 50V C0G, NP0 Ceramic Capacitor -55°C ~ 125°C Surface Mount, MLCC 0402 (1005 Metric) 0.039" L x 0.020" W (1.00mm x 0.50mm)
24 | 1200pF, 50V | 1 | C390 | CAP0402 | Kemet | C0402C122J5GACTU | Digi-Key | 399-7334-1-ND | 1200pF ±5% 50V C0G, NP0 Ceramic Capacitor -55°C ~ 125°C Surface Mount, MLCC 0402 (1005 Metric) 0.039" L x 0.020" W (1.00mm x 0.50mm)
25 | 22nF, 50V | 2 | C391, C413 | CAP0402 | Kemet | C0402C223K5RACTU | Digi-Key | 399-7780-1-ND | 0.022µF ±10% 50V X7R Ceramic Capacitor -55°C ~ 125°C Surface Mount, MLCC 0402 (1005 Metric) 0.039" L x 0.020" W (1.00mm x 0.50mm)
26 | 68pF, 25V | 1 | C411 | CAP0402 | Kemet | CBR04C680F3GAC | Digi-Key | 399-11255-1-ND | 68pF ±1% 25V C0G, NP0 Ceramic Capacitor -55°C ~ 125°C Surface Mount, MLCC 0402 (1005 Metric) 0.039" L x 0.020" W (1.00mm x 0.50mm)
27 | 1500pF, 50V | 1 | C412 | CAP0402 | Samsung Electro-Mechanics America, Inc. | CL05B152KB5NNNC | Digi-Key | 1276-1521-1-ND | 1500pF ±10% 50V X7R Ceramic Capacitor -55°C ~ 125°C Surface Mount, MLCC 0402 (1005 Metric) 0.039" L x 0.020" W (1.00mm x 0.50mm)
28 | Fiducial | 4 | F1, F2, F3, F4 | Fiducial
29 | 600R, 0.27A | 38 | FR1, FR2, FR3, FR4, FR5, FR6, FR7, FR8, FR9, FR10, FR11, FR12, FR13, FR14, FR15, FR16, FR17, FR18, FR19, FR20, FR21, FR22, FR23, FR24, FR25, FR26, FR27, FR28, FR29, FR30, FR31, FR32, FR33, FR34, FR35, FR38, FR39, FR55 | RES0201 | Taiyo Yuden | BK0603TS601-T | Digi-Key | 587-3277-1-ND | FERRITE BEAD 600 OHM 0201 1LN | NF(FR18 FR25)
30 | 600R, 2A | 25 | FR36, FR37, FR40, FR41, FR42, FR43, FR44, FR45, FR46, FR47, FR48, FR49, FR50, FR51, FR52, FR53, FR54, FR56, FR57, FR58, FR59, FR60, FR61, FR62, FR63 | RES0805 | TDK Corporation | MPZ2012S601AT000 | Digi-Key | 445-2206-2-ND | FERRITE BEAD 600 OHM 0805 1LN | NF(FR42 FR43)
31 | LMS7002M | 1 | IC1 | LMS7002M_v2 | Lime Microsystems | LMS7002M | Lime Microsystems | LMS7002M | IC FPRF Transceiver LMS7002M; 261 pin aQFN
32 | 24FC64F | 2 | IC2, IC18 | 24FC512 | Microchip Technology | 24FC64F-I/ST | Digi-Key | 24FC64F-I/ST-ND | IC EEPROM 512KBIT 1MHZ 8TSSOP
33 | 24FC512 | 1 | IC3 | 24FC512 | Microchip Technology | 24FC512-I/ST | Digi-Key | 24FC512-I/ST-ND | IC EEPROM 512KBIT 1MHZ 8TSSOP
34 | SKY13323 | 4 | IC4, IC5, IC6, IC7 | SKY13323-378LF | Skyworks Solutions Inc. | SKY13323-378LF | Digi-Key | 683-1334-1-ND | IC SPDT 100MHZ-3GHZ 6-MLPD
35 | EP4CE40F23C8N | 1 | IC8 | FBGA484_A-240 | Altera | EP4CE40F23C8N | Digi-Key | 544-2811-ND | IC FPGA 328 I/O 484FBGA
36 | TS3A5018PWR | 1 | IC9 | TS3A5018PWR | TEXAS INSTRUMENTS | TS3A5018PW | Newark | 71J8329 | IC SWITCH QUAD SPDT 16TSSOP
37 | M25P16 | 1 | IC10 | M25P40-VMN6TPB_SO8N | Micron Technology Inc. | M25P16-VMN6P | Farnell | 1734973 | IC FLASH 16MBIT 75MHZ 8SO
38 | AS4C64M16D2-25BCN | 2 | IC11, IC12 | AS4C64M16D2 | Alliance Memory, Inc. | AS4C64M16D2-25BCN | Digi-Key | 1450-1158-ND | IC SDRAM 64MX16 1.8V 84-FBGA
39 | CYUSB3014-BZXC | 1 | IC13 | CYP-BZX121 | Cypress Semiconductor Corp | CYUSB3014-BZXC | Digi-Key | 428-3182-ND | EZ-USB(R) FX3: SuperSpeed USB Controller, 512 KB, 60 I/Os, 0 to 70 degC, 121-Pin FBGA (BZX121)
40 | SP3010-04UTG | 1 | IC14 | SP3010-04UTG | Littelfuse Inc | SP3010-04UTG | Digi-Key | F3507TR-ND | TVS DIODE 6VWM 12.3VC UDFN
41 | M25P40 | 1 | IC15 | M25P40-VMN6TPB_SO8N | Micron Technology Inc | M25P40-VMN6TPB | Digi-Key | M25P40-VMN6TPBTR-ND | IC FLASH 4MBIT 75MHZ 8SO
42 | LM75 | 1 | IC16 | HWSON8_LM75 | NXP Semiconductors | LM75BTP,147 | Digi-Key | 568-9815-2-ND | SENSOR TEMPERATURE I2C 8HWSON
43 | MAX7322 | 1 | IC17 | MAX7322ATE_QFN16 | Maxim Integrated | MAX7322ATE+ | Digi-Key | MAX7322ATE+-ND | IC I/O EXPANDER I2C 4B 16TQFN
44 | SC18IS602B | 1 | IC19 | SC18IS602B_TSSOP16 | NXP Semiconductors | SC18IS602BIPW,112 | Digi-Key | 568-4785-5-ND | IC BRIDGE SPI/I2C 16-TSSOP | NF(IC19)
45 | LMK00105 | 1 | IC20 | LMK00105SQ | Texas Instruments | LMK00105SQ/NOPB | Digi-Key | LMK00105SQ/NOPBCT-ND | IC CLK BUFFER 2:5 200MHZ 24WQFN
46 | NC7SV74K8XCT | 1 | IC21 | NC7SV74K8XCT | Fairchild Semiconductor | NC7SV74K8X | Digi-Key | NC7SV74K8XCT-ND | IC D-TYPE POS TRG SNGL US8 | NF(IC21)
47 | AD5601BKSZ-REEL7 | 1 | IC22 | AD5601_SOT23-6 | Analog Devices | AD5601BKSZ-REEL7 | Digi-Key | AD5601BKSZ-REEL7TR-ND | IC DAC 8BIT BUFF V-OUT SC70-6
48 | ADF4002 | 1 | IC23 | ADF4002 | Analog Devices Inc | ADF4002BCPZ-RL7 | Digi-Key | ADF4002BCPZ-RL7CT-ND | IC PLL FREQUENCY SYNTH 20-LFCSP
49 | Si5351C | 1 | IC24 | Si5351C_20QFN | Silicon Labs | SI5351C-B-GM | Digi-Key | 336-2402-ND | IC CLK GENERATOR 200MHZ 20QFN
50 | FPF3042 | 1 | IC25 | FPF3042 | Fairchild Semiconductor | FPF3042UCX | Digi-Key | FPF3042UCXCT-ND | IC OR CTRLR SRC SELECT 16WLCSP
51 | AP7361-FGE | 6 | IC26, IC28, IC30, IC32, IC33, IC34 | AP7361 | Diodes Incorporated | AP7361-FGE-7 | Digi-Key | AP7361-FGE-7DICT-ND | IC REG LDO ADJ 1A 8DFN
52 | ADP2386 | 2 | IC27, IC31 | ADP2386 | Analog Devices Inc. | ADP2386ACPZN-R7 | Digi-Key | ADP2386ACPZN-R7DKR-ND | IC REG BUCK ADJ 6A SYNC 24LFCSP
53 | RT9026 | 1 | IC29 | MSOP10 | Richtek USA Inc. | RT9026GFP | Digi-Key | 1028-1010-1-ND | IC DDR TERMINATION REG 10MSOP
54 | LP38503TS | 1 | IC35 | TO-263-5_v2 | Texas Instruments | LP38503TS-ADJ/NOPB | Digi-Key | LP38503TS-ADJ/NOPB-ND | IC REG LDO ADJ 3A TO263-5
55 | SPX3819R2 | 1 | IC36 | SPX3819R2-L/TR | Exar Corporation | SPX3819R2-L/TR | Digi-Key | 1016-1588-1-ND | Linear Voltage Regulator IC Positive Adjustable 1 Output Adjustable 500mA 8-DFN (2x3)
56 | U.FL/MMCX | 12 | J1, J2, J3, J4, J5, J6, J7, J8, J9, J10, J18, J19 | MMCX_UFL_conn_u | Molex, LLC | 0734120110 | Digi-Key | WM5587CT-ND | CONN UMC RCPT STR 50 OHM SMD
57 | FPGA JTAG | 1 | J11 | SWD_10_pin | Harwin Inc | M50-3600542 | Digi-Key | 952-1389-ND | CONN HDR 1.27MM SMD AU 10POS
58 | FPGA GPIO | 1 | J12 | SWD_10_pin | Harwin Inc | M50-3600542 | Digi-Key | 952-1389-ND | CONN HDR 1.27MM SMD AU 10POS
59 | FAN | 1 | J13 | HDR_1x2 | 3M | 961102-6404-AR | Digi-Key | 3M9447-ND | 2 Positions Header, Unshrouded Connector 0.100" (2.54mm) Through Hole Gold | NF(J13)
60 | FAN | 1 | J14 | HDR_1x2_HALF_PITCH | Sullins Connector Solutions | GRPB021VWVN-RC | Digi-Key | S9014E-02-ND | CONN SHUNT 1.27MM BLUE W/HANDLE
61 | Micro_USB3B | 1 | J15 | microUSB3B_SM_v2 | Amphenol Commercial Products | GSB443T33HR | Digi-Key | GSB443T33HRCT-ND | USB - micro B USB 3.1, Superspeed+ Receptacle Connector 10 Position Surface Mount, Right Angle
62 | FX3 JTAG | 1 | J16 | SWD_10_pin | Harwin Inc | M50-3600542 | Digi-Key | 952-1389-ND | CONN HDR 1.27MM SMD AU 10POS
63 | Jumper | 1 | J17 | HDR_1x2_HALF_PITCH | Sullins Connector Solutions | GRPB021VWVN-RC | Digi-Key | S9014E-02-ND | 2 Positions Header, Unshrouded Connector 0.050" (1.27mm) Through Hole Gold
64 | Mating Diameter: 1.30mm ID (0.051"), 3.50mm OD (0.138") | 1 | J20 | CONN_PWR_JACK_v4 | CUI Inc. | PJ-031DH | Digi-Key | CP-031DH-ND | Power Barrel Connector Jack 1.30mm ID (0.051"), 3.50mm OD (0.138") Through Hole, Right Angle
65 | Header 3x1 pin | 1 | J21 | HDR_1x3 | Amphenol FCI | 68000-103HLF | Digi-Key | 609-3461-ND | 3 Positions Header, Unshrouded Connector 0.100" (2.54mm) Through Hole Gold or Gold, GXT | NF(J21)
66 | 1 pcs. | 1 | JMP1 | MECH_JUMPER_HALF_PITCH | Harwin Inc. | M50-2030005 | Digi-Key | 952-1732-ND | CONN SHUNT 1.27MM BLUE W/HANDLE
67 | 1.5uH | 1 | L1 | FDVE1040_TOKO_INDUCTOR | Vishay Dale | IHLP4040DZER1R5M01 | Digi-Key | 541-1301-6-ND | FIXED IND 1.5UH 15A 5.8 MOHM SMD
68 | 1uH | 1 | L2 | FDVE1040_TOKO_INDUCTOR | Vishay Dale | IHLP3232DZER1R0M01 | Digi-Key | 541-1371-6-ND | FIXED IND 1UH 18A 5.78 MOHM SMD
69 | LED_RG_SMD | 4 | LED1, LED2, LED7, LED8 | LED-2x0603 | Avago Technologies US Inc. | HSMF-C165 | Digi-Key | 516-1419-1-ND | LED GREEN/RED DIFFUSED 0603 SMD
70 | LED_RG | 4 | LED3, LED4, LED5, LED6 |  | Visual Communications Company - VCC | 4301F1/5 | Digi-Key | 4301F1/5-ND | LED GRN/RED DIFF 3MM ROUND T/H | NF(LED3 LED4 LED5 LED6)
71 | 2xLED standoff | 2 | LEDS1, LEDS2 | LED_STANDOFF_H-201C | Bivar Inc. | H-201C | Digi-Key | 492-1790-ND | LED HOLDER RA 3MM 2LD NYL BK | NF(LEDS1 LEDS2)
72 | # pcs. | 4 | MECH1, MECH2, MECH3, MECH4 | PCB_standoff | FIX&FASTEN | FIX-MAE-5TV | TME | FIX-MAE-5TV | PCB distance; polyamide; L:5mm; Colour: natural; Øcutout:3mm
73 | 100uH | 4 | MN1, MN2, MN29, MN30 | RES0805 | TDK Corporation | MLF2012C101KT000 | Digi-Key | 445-1071-1-ND | FIXED IND 100UH 2MA 3.1 OHM SMD
74 | 47nH | 4 | MN3, MN4, MN31, MN32 | RES0402 | COILCRAFT | 0402HP-47NXJLU | Farnell | 2285856 | INDUCTOR, RF, 47NH, 5%, 2.4GHZ, SMD; Product Range:0402HP Series; Inductance:47nH; Inductance Tolerance:± 5%; High Frequency Inductor Case:0402 [1005 Metric]; Self Resonant Frequency Min:2.4GHz; DC Resistance Max:0.58ohm; DC Current Rating:420mA
75 | 0.5pF | 6 | MN6, MN15, MN22, MN34, MN43, MN50 | CAP0402 | Yageo | CC0402CRNPO9BNR50 | Digi-Key | 311-1001-1-ND | 0.50pF ±0.25pF 50V C0G, NP0 Ceramic Capacitor -55°C ~ 125°C Surface Mount, MLCC 0402 (1005 Metric) 0.039" L x 0.020" W (1.00mm x 0.50mm) | NF(MN6 MN22 MN34 MN50)
76 | 2pF | 6 | MN7, MN21, MN24, MN35, MN49, MN52 | CAP0402 | AVX | 04025U2R0BAT2A | Farnell | 2332536 | 2pF ±0.1pF 50V C0G, NP0 Ceramic Capacitor -55°C ~ 125°C Surface Mount, MLCC 0402 (1005 Metric) 0.039" L x 0.020" W (1.00mm x 0.50mm)
77 | 0uH (0R) | 4 | MN9, MN10, MN37, MN38 | RES0805 | BOURNS | CR0805-J/-000ELF | Farnell | 2008388 | RES SMD 0.0 OHM JUMPER 1/8W 0805
78 | 8.2nH, 5% | 6 | MN11, MN12, MN18, MN39, MN40, MN46 | RES0402 | COILCRAFT | 0402HP-8N2XJLU | Farnell | 2285826 | INDUCTOR, RF, 8.2NH, 5%, 5.4GHZ, SMD; Product Range:0402HP Series; Inductance:8.2nH; Inductance Tolerance:± 5%; High Frequency Inductor Case:0402 [1005 Metric]; Self Resonant Frequency Min:5.4GHz; DC Resistance Max:0.065ohm; DC Current Rating:1.5A
79 | 0.8pF | 6 | MN13, MN16, MN27, MN41, MN44, MN55 | CAP0402 | Murata Electronics North America | GRM1555C1HR80BA01D | Digi-Key | 490-6269-1-ND | 0.80pF ±0.1pF 50V C0G, NP0 Ceramic Capacitor -55°C ~ 125°C Surface Mount, MLCC 0402 (1005 Metric) 0.039" L x 0.020" W (1.00mm x 0.50mm)
80 | 1pF | 4 | MN14, MN23, MN42, MN51 | CAP0402 | TDK Corporation | C1005C0G1H010B050BA | Digi-Key | 445-4854-6-ND | 1pF ±0.1pF 50V C0G, NP0 Ceramic Capacitor -55°C ~ 125°C Surface Mount, MLCC 0402 (1005 Metric) 0.039" L x 0.020" W (1.00mm x 0.50mm) | NF(MN14 MN42)
81 | 510pF | 4 | MN17, MN20, MN45, MN48 | CAP0402 | Murata Electronics North America | GRM1555C1H511JA01D | Digi-Key | 490-3237-1-ND | 510pF ±5% 50V C0G, NP0 Ceramic Capacitor -55°C ~ 125°C Surface Mount, MLCC 0402 (1005 Metric) 0.039" L x 0.020" W (1.00mm x 0.50mm)
82 | 1.2pF | 2 | MN19, MN47 | CAP0402 | Murata Electronics North America | GRM1555C1H1R2CA01D | Digi-Key | 490-5927-1-ND | 1.2pF ±0.25pF 50V C0G, NP0 Ceramic Capacitor -55°C ~ 125°C Surface Mount, MLCC 0402 (1005 Metric) 0.039" L x 0.020" W (1.00mm x 0.50mm)
83 | 10nH, 5% | 2 | MN26, MN54 | RES0402 | COILCRAFT | 0402HP-10NXJLU | Farnell | 2285830 | INDUCTOR, RF, 10NH, 5%, 4.7GHZ, SMD; Product Range:0402HP Series; Inductance:10nH; Inductance Tolerance:± 5%; High Frequency Inductor Case:0402 [1005 Metric]; Self Resonant Frequency Min:4.7GHz; DC Resistance Max:0.11ohm; DC Current Rating:1.3A
84 | 10k, 1% | 38 | R1, R2, R3, R4, R5, R10, R11, R48, R49, R50, R55, R58, R66, R67, R103, R104, R105, R115, R116, R117, R119, R125, R127, R128, R129, R130, R132, R133, R160, R161, R180, R186, R187, R195, R200, R205, R207, R211 | RES0402 | Yageo | RC0402FR-0710KL | Digi-Key | 311-10.0KLRTR-ND | RES SMD 10K OHM 1% 1/16W 0402 | NF(R49 R67 R116 R119)
85 | 49.9R, 1% | 16 | R6, R7, R8, R9, R46, R47, R140, R152, R159, R163, R164, R165, RA3, RA4, RA7, RA8 | RES0402 | Samsung Electro-Mechanics America, Inc. | RC1005F49R9CS | Digi-Key | 1276-3469-6-ND | RES SMD 49.9 OHM 1% 1/16W 0402
86 | 2k2, 1% | 2 | R12, R13 | RES0402 | Stackpole Electronics Inc | RMCF0402FT2K20 | Digi-Key | RMCF0402FT2K20CT-ND | RES SMD 2.2K OHM 1% 1/16W 0402
87 | 100R, 1% | 15 | R14, R16, R17, R18, R20, R21, R76, R79, R80, R82, R85, R86, R168, R169, R170 | RES0402 | Stackpole Electronics Inc. | RMCF0402FT100R | Digi-Key | RMCF0402FT100RDKR-ND | RES SMD 100 OHM 1% 1/16W 0402
88 | 1k, 1% | 13 | R15, R19, R62, R131, R134, R135, R154, R174, R179, R190, R193, R198, R203 | RES0402 | Stackpole Electronics Inc | RMCF0402FT1K00 | Digi-Key | RMCF0402FT1K00TR-ND | RES SMD 1K OHM 1% 1/16W 0402 | NF(R15 R19)
89 | 0R | 69 | R22, R23, R24, R25, R26, R27, R28, R29, R30, R42, R43, R44, R45, R51, R52, R53, R54, R56, R57, R59, R60, R61, R63, R64, R65, R72, R74, R92, R106, R107, R108, R110, R111, R112, R113, R120, R122, R124, R136, R137, R138, R139, R141, R142, R143, R144, R145, R146, R147, R148, R149, R150, R151, R155, R157, R158, R166, R167, R173, R176, R177, R178, R188, R191, R192, R202, R204, R208, R212 | RES0402 | Yageo | RC0402JR-070RL | Digi-Key | 311-0.0JRTR-ND | RES SMD 0.0OHM JUMPER 1/16W 0402 | NF(R52 R53 R57 R60 R63 R65 R74 R92 R111 R120 R122 R124 R141 R143 R144 R145 R146 R147 R148 R149 R151 R155 R166 R167 R177 R212)
90 | 0R | 7 | R31, R32, R34, R35, R36, R37, R38 | RES0201 | Rohm Semiconductor | MCR006YRTJ000 | Digi-Key | RHM0.0CCCT-ND | RES SMD 0.0OHM JUMPER 1/20W 0201
91 | 10R | 4 | R33, R39, R40, R41 | RES0201 | Panasonic Electronic Components | ERJ-1GEF10R0C | Digi-Key | P10.0ABCT-ND | RES SMD 10 OHM 1% 1/20W 0201
92 | 22R | 3 | R68, R98, R99 | RES0402 | Yageo | RC0402FR-0722RL | Digi-Key | 311-22.0LRTR-ND | RES SMD 22 OHM 1% 1/16W 0402
93 | 100K | 3 | R69, R114, R118 | RES0402 | Panasonic Electronic Components | ERJ-2GEJ104X | Digi-Key | P100KJCT-ND | RES SMD 100K OHM 5% 1/10W 0402
94 | 4K7 | 6 | R70, R71, R73, R121, R123, R126 | RES0402 | Stackpole Electronics Inc. | RMCF0402JT4K70 | Digi-Key | RMCF0402JT4K70TR-ND | RES SMD 4.7K OHM 5% 1/16W 0402
95 | 8x56R | 6 | R75, R77, R78, R81, R83, R84 | EXB2HV | PANASONIC ELECTRONIC COMPONENTS | EXB2HV560JV | Farnell | 2060070 | RES ARRAY 8 RES 56 OHM 1506
96 | 22R | 11 | R87, R88, R89, R90, R91, R94, R96, R97, R100, R101, R102 | ChipResistorArray | Yageo | YC124-JR-0722RL | Digi-Key | YC124J-22TR-ND | RES ARRAY 4 RES 22 OHM 0804
97 | 6.04K, 1% | 1 | R93 | RES0402 | Rohm Semiconductor | MCR01MRTF6041 | Digi-Key | RHM6.04KCDTR-ND | RES SMD 6.04K OHM 1% 1/16W 0402
98 | 200R, 1% | 1 | R95 | RES0402 | Stackpole Electronics Inc | RMCF0402FT200R | Digi-Key | RMCF0402FT200RDKR-ND | RES SMD 200 OHM 1% 1/16W 0402
99 | 2.21k, 1% | 2 | R109, R184 | RES0402 | Stackpole Electronics Inc. | RMCF0402FT2K21 | Digi-Key | RMCF0402FT2K21CT-ND | RES SMD 2.21K OHM 1% 1/16W 0402
100 | 10R, 5% | 1 | R153 | RES0402 | Yageo | RC0402JR-0710RL | Digi-Key | 311-10JRTR-ND | RES SMD 10 OHM 5% 1/16W 0402
101 | 470R, 0.5% | 2 | R156, R175 | RES0402 | Panasonic Electronic Components | ERA-2AED471X | Digi-Key | P470DETR-ND | RES SMD 470 OHM 0.5% 1/16W 0402
102 | 330R, 5% | 1 | R162 | RES0402 | Yageo | RC0402JR-07330RL | Digi-Key | 311-330JRTR-ND | RES SMD 330 OHM 5% 1/16W 0402
103 | 249R, 1% | 1 | R171 | RES0402 | Stackpole Electronics Inc | RMCF0402FT249R | Digi-Key | RMCF0402FT249RCT-ND | RES SMD 249 OHM 1% 1/16W 0402
104 | 0R | 1 | R172 | RES0805 | Vishay Dale | CRCW08050000Z0EA | Digi-Key | 541-0.0ATR-ND | RES SMD 0.0 OHM JUMPER 1/8W 0805 | NF(R172)
105 | 44.2k, 1% | 3 | R181, R185, R196 | RES0402 | Panasonic Electronic Components | ERJ-2RKF4422X | Digi-Key | P44.2KLCT-ND | RES SMD 44.2K OHM 1% 1/10W 0402 | NF(R181 R196)
106 | 806R, 1% | 3 | R182, R197, R206 | RES0402 | Stackpole Electronics Inc | RMCF0402FT806R | Digi-Key | RMCF0402FT806RCT-ND | RES SMD 806 OHM 1% 1/16W 0402
107 | 100k, 5% | 1 | R183 | RES0402 | Panasonic Electronic Components | ERJ-2GEJ104X | Digi-Key | P100KJTR-ND | RES SMD 100K OHM 5% 1/10W 0402
108 | 750R, 1% | 1 | R189 | RES0402 | Yageo | RC0402FR-07750RL | Digi-Key | 311-750LRCT-ND | RES SMD 750 OHM 1% 1/16W 0402
109 | 560R, 1% | 3 | R194, RA1, RA5 | RES0402 | Vishay Dale | CRCW0402560RFKED | Digi-Key | 541-560LCT-ND | RES SMD 560 OHM 1% 1/16W 0402
110 | 124k, 1% | 1 | R199 | RES0402 | Panasonic Electronic Components | ERJ-2RKF1243X | Digi-Key | P124KLCT-ND | RES SMD 124K OHM 1% 1/10W 0402
111 | 66.5k, 1% | 1 | R201 | RES0402 | Panasonic Electronic Components | ERJ-2RKF6652X | Digi-Key | P66.5KLDKR-ND | RES SMD 66.5K OHM 1% 1/10W 0402
112 | 39k, 1% | 1 | R209 | RES0402 | Yageo | RC0402FR-0739KL | Digi-Key | 311-39.0KLRCT-ND | RES SMD 39K OHM 1% 1/16W 0402
113 | 23.2k, 1% | 1 | R210 | RES0402 | Yageo | RC0402FR-0723K2L | Digi-Key | YAG3066CT-ND | RES SMD 23.2K OHM 1% 1/16W 0402
114 | 2.49k, 1% | 2 | RA2, RA6 | RES0402 | Yageo | RC0402FR-072K49L | Digi-Key | 311-2.49KLRDKR-ND | RES SMD 2.49K OHM 1% 1/16W 0402
115 | Switch, tactile | 1 | SW1 | SW_tactile | Omron Electronics Inc-EMC Div | B3U-1000P | Digi-Key | SW1020TR-ND | SWITCH TACTILE SPST-NO 0.05A 12V
116 | TC1-1-13MA+ | 6 | T1, T3, T5, T6, T8, T10 | TC1-1-13MA+_v2 | Mini-Circuits | TC1-1-13MA+ | Minicircuits | TC1-1-13MA+ | RF balun, TC1-1-13MA+
117 | TCM1-63AX+ | 4 | T2, T4, T7, T9 | TCM1-63AX+_v2 | Mini-circuits | TCM1-63AX+ | Minicircuits | TCM1-63AX+ | RF balun, TCM1-63AX+
118 | SK36A | 1 | VD1 | DIODE_SMB | Micro Commercial Co | SK36A-LTP | Digi-Key | SK36A-LTPMSCT-ND | DIODE SCHOTTKY 60V 3A DO214AC
119 | RF MOSFET | 6 | VT1, VT2, VT3, VT4, VT5, VT6 | BF1105R_SOT143R4 | NXP Semiconductors | BF1105R,215 | Digi-Key | 568-12530-6-ND | RF MOSFET Transistors Trans MOSFET N-CH 7V 0.03A 4pin(3+Tab)
120 | NDS331N | 1 | VT7 | SOT23-3 | Fairchild Semiconductor | NDS331N | Digi-Key | NDS331NCT-ND | MOSFET N-CH 20V 1.3A SSOT3
121 | 30.72 MHz | 1 | XO1 | RAKON_RPT7050A | Rakon | E6245LF | Rakon | E6245LF | TCXO 30.72MHz, E6245LF | NF(XO1)
122 | TCXO 30.72MHz | 1 | XO2 | RAKON_TXCO | Rakon | E5280LF | Rakon | E5280LF | TCXO 30.72MHz, E5280LF
123 | 19.2MHz | 1 | XT1 | CRYSTAL_4-LCC_v2 | CTS-Frequency Controls | 405C35B19M20000 | Digi-Key | CTX648CT-ND | 19.2MHz ±30ppm Crystal 13pF 60 Ohm -20°C ~ 70°C Surface Mount 4-SMD, No Lead (DFN, LCC)
124 | 25MHz | 1 | XT2 | CRYSTAL_4-LCC | ABRACON | ABM8-25.000MHZ-B2-T | Newark | 13J1767 | 25MHz ±20ppm Crystal 18pF 50 Ohm -20°C ~ 70°C Surface Mount 4-SMD, No Lead (DFN, LCC)
 |  |  |  |  |  |  |  |  |  | Total NF element number: 60
 |  |  |  |  |  |  |  |  |  | All NF elements in one row:
 |  |  |  |  |  |  |  |  |  | NF(C341 C324 C325 C142 FR18 FR25 FR42 FR43 J13 J21 LED3 LED4 LED5 LED6 LEDS1 LEDS2 MN6 MN22 MN34 MN50 MN14 MN42 R49 R67 R116 R119 R15 R19 R52 R53 R57 R60 R63 R65 R74 R92 R111 R120 R122 R124 R141 R143 R144 R145 R146 R147 R148 R149 R151 R155 R166 R167 R177 R212 R172 R181 R196 XO1 IC19 IC21)
 |  |  |  |  |  |  |  |  |  | *NOTE: NF(R1 R2) means that elements R1 and R2 are unpopulated (NF)

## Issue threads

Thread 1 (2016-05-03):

TX/RX frequency range documentation

alexwhittemore, 2016-05-03:
This isn't _necessarily_ an issue, but for lack of a better place to discuss, I'll ask here: the LimeSDR is advertised with a working frequency range from 100kHz to 3.8GHz, but the schematic notes on the RF matching networks don't match this. I'm assuming (speaking of RX) that "RXRF2_L" is "low frequency", "_H" is "high frequency," and "_W" is "wideband." I suppose the overlap is to allow for mechanical design flexibility (using a single connection and antenna for full coverage) at the price of receive signal strength? Beyond that, both L+H and W seem to cover only 700MHz to 2.6GHz. Given my poor RF design skills, I don't know just looking at the matching networks if that's shorthand, or if those matching networks actually roll off sharply at those bounds and I'm missing something else. So I guess, what's the deal?

ztamosevicius, 2016-05-04:
This is just a RF matching question. It may be tuned to lower frequencies using different components.

alexwhittemore, 2016-05-04:
I guess the point is, is it a question of poor performance, or is it "you must modify the networks yourself to use the board at 100kHz"?

2ftg, 2016-05-06:
The RF matching components are size 0402.
So while doable with a steady hand and sharp eye, we are getting in to the microscope, micro tweezers and preheater territory.
While I might be ready to stack some caps on top of the existing 100nF one's for improved LF response, I'm unsure how many others would be ready to do so.

Some stuff based on reading the schematics and googling:
TC1-1-13MA+ balun transformer is used for 30 MHz-1.9 GHz branch, 700 MHz-900 MHz branch and on the 700 MHZ-2.6 GHz branch. Both TX and RX.
Datasheet shows that it is specified for 4.5 to 3000 MHz. https://www.minicircuits.com/pdfs/TC1-1-13MA+.pdf

TCM1-63AX+ balun transformer is used in the 2-2.6 GHz branches for both TX and RX.
Datasheet shows that it is specified for 10 to 6000 MHz.  https://www.minicircuits.com/pdfs/TCM1-63AX+.pdf

The coupling caps in the 30 MHz-1.9 GHz branch are 100nF, which should be usable on HF, but might be too little at LF.
I think the HF branch should work well for most of the HF bands and the 700-900 MHz branch should also work reasonably on 2m/70cm.
If the LimeSDR folks say that it will cover 100kHz-3.8GHz I'd say it does it, but the performance might be degraded at the band edges, this is my guess as an amateur and general radio hobbyist.
Here's a screencapture of the RF section for those without Altium or windows to run Altium viewer. https://i.imgur.com/GhfW6vr.png
I don't do RF design professionally nor do I represent the LimeSDR project in anyway. So take what I say with a grain of salt.

alexwhittemore, 2016-05-06:
Thanks for the analysis! Better info than I'd have come up with.

Unrelated to the RF side of things, if you ever find yourself having to do a rework on components like that at your bench at home with a pretty-good-but-not-pro soldering station, get some ChipQuick. The stuff is seriously magical.

heitorPB, 2019-06-25:
Are there any real tests at very low frequencies so we can check it?

ztamosevicius, 2019-06-26:
Check this:
https://myriadrf.org/news/optimising-limesdr-matching-hf/

Jelly478558074, 2020-05-18:
LimeSDR USB，What is the name of the transmitting antenna?

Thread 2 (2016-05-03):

Duplicated channel naming in schematic

alexwhittemore, 2016-05-03:
On 05_LMS7002M_RF.SchDoc, the note "TXRF1_A" is duplicated twice. On the left, it looks like it should be as-is, and on the right (IC1 Part 5/5, attached to pins pa1op_2 and pa1on_2) I think it should be TXRF1_B.

ztamosevicius, 2016-05-04:
Correct. It should be TXRF1_B next to the J2 connector.
Thanks for the note!

ztamosevicius, 2019-06-26:
Fixed in v1.4 version.

Closed 2019-06-26.

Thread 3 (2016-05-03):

Confusing TX channel labeling

alexwhittemore, 2016-05-03:
Each of the two TX channels has two independent power amplifiers, with independent outputs, feeding independent matching networks for high and low frequency range.

It makes most sense to me to number the mutually exclusive channels, and to letter the frequency divisions of them.

Specifically: (as-is name > proposed name)
TXRF1_A > TX1_L
TXRF1_B > TX2 _L
TXRF2_A > TX1_H
TXRF2_B > TX2_H

In fact, per current schematic, the net naming consistency seems poor - the channel noted "TXRF1_A" contains differential nets prefixed with "TXRF1," but so does the channel noted "TXRF2_A" right below it. This would be consistent with my "numbers for channels" convention requested above, but isn't consistent with the "letters for channels" convention currently in silk.

ztamosevicius, 2016-05-04:
Agree. It will be improved for the next versions.
Thanks for review!

luftek, 2016-11-07:
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

Improved with latest commit 3d4a8c1e5b6626482928e8b3cf6abc6add5ede07

ztamosevicius, 2019-06-26:
Improved in v1.4 version.

Closed 2019-06-26.

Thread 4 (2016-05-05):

Repository authority?

alexwhittemore, 2016-05-05:
I'm guessing this repo is curated to be public-facing and doesn't represent whatever internal version control is being used in active development? The real thrust of my question is whether it's worth forking, contributing, and pull-requesting, or if this repository is going to be non-authoritative for the purpose of shielding intermediate development from the public. Are there plans to use this repo for active development in the future, or is it always likely to be a limited-commit public face?

9600, 2016-05-10:
Good question! The plan is very much for these to be the authoritative/master repos and pull requests are encouraged — we'd love to have contributions to improving the platform. We obviously need to have at least some sort of basic policy in place and this is something that we hope to announce in the not too distant future.

alexwhittemore, 2016-05-10:
Great to hear! Although that does raise some concerns about _how_ community members can contribute, given that the project is designed in Altium. CircuitMaker, in Altium's closed-ecosystem wisdom, won't open offline projects, and the $10k/seat price tag of AD16 is going to keep non-professionals away. As it happens, I personally use Altium on a daily basis at work, but then there's still the question of using corporate resources for open source contributions, which I imagine will be a hangup for many. On the one hand, this may effectively filter contributions to only professional engineers. On the other hand, that may well not be what you actually want. Thoughts on addressing those kinds of issues?

9600, 2016-05-19:
If you look at the majority of the other Myriad-RF projects you will see that KiCAD databases have been published for them. It's always been the plan to make LimeSDR available as a KiCAD design also and it's just a question of time and resources (which are currently focused on the driver, apps and campaign etc.)

alexwhittemore, 2016-05-22:
Ahh, I hadn't actually dug in enough to see that. So I suppose, follow-on question, at such a time as you have resources to pay off the technical debt of converting over, presumably the replacement KiCad projects become canonical?

9600, 2016-05-23:
Good question and we might need to figure out a practical workflow to support contributions. For example, KiCAD will lack certain features that are highly beneficial when doing impedance matched RF layout, and so then how would you "round trip" the design between two tools? But perhaps more than this, we'll need to figure out what the criteria are for accepting pull requests that update the hardware design.

Updates to the hardware platform are obviously very different to updates to the host driver, FX3 and FPGA firmware, since there are very different implications, notably the cost involved in validation/testing and manufacturing. I could, for example, imagine a situation whereby we might have a branch with a derivative design of some merit, that has not been validated — i.e. physically built and put through its paces — by Lime Micro. However, others would be at liberty to do this. But then if someone proposes a great and eminently practical improvement to the hardware platform, it would clearly make sense to try and incorporate this.

Closed 2019-06-26.

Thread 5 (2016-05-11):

DDR reference plane

gitmodimo, 2016-05-11:
Not all DDR signals have continuous reference plane. Signals on layer L4 L8 L9 from DDR to FPGA are crossing split plane.

There are many references to that requirement:
4.1 http://www.ti.com/lit/an/spraaw8a/spraaw8a.pdf
25. http://www.nxp.com/files/32bit/doc/app_note/AN2910.pdf

Also clearance between polygon and DDR signals should be bigger.

alexwhittemore, 2016-05-11:
Good catch! Although this might fall into the category of 'it works so, meh' - the memory is laid out very close to the FPGA, and it's pretty slow as modern technologies go, and there IS a continuous ground plane, just not on an immediately adjacent layer. The manufacturing notes only specify impedance control for USB 3 and RF between layers 1>2 and 11>bottom, so it looks like the memory isn't even designed to use impedance controlled routing, only length-matched. Which strikes me as fine - even given aggressive timing considerations, the trace length is well under a 1ns rise time in terms of propagation delay.

Plus, correct me if I'm wrong - I think this board's already been manufactured and is used in the wild, so unless there are memory errors showing up, it looks like real-world testing probably rules it out as problematic.

gitmodimo, 2016-05-11:
I am not sure, but it seems that the boards are 'in the wild'. And yes if it works it is no need to change. But as for the FPGA project on github there is no DDR controller instantiation. In other words the firmware in current version does not use DDR at all. So that brings up the question whether it works. Are there any confirmed successful memtests?

alexwhittemore, 2016-05-11:
Interesting, that doesn't inspire confidence, then. I suppose for the basic SDR use-case, it's not used? All the data is just piped directly through the USB controller. So you could be right, maybe it's just as-yet untested.

ztamosevicius, 2016-05-12:
Exactly, for this use-case there is no need for external memories.
External memories are tested using massive write-read and compare procedure. No issues found so far.

gitmodimo, 2016-05-12:
Thanks ztamosevicius. I think that settles it.

alexwhittemore, 2016-05-12:
Hey, look at that, first closed issue :)

Closed 2016-05-12.

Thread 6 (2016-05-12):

micro USB 3.0 Type B

luftek, 2016-05-12:
BOM for hardware/plug/1v2 is valid from initial commit?
`I already ordered micro usb connectors for my sample alu enclosure :)`

luftek, 2016-05-13:
I don't know why I didn't check your folder for socket from the beginning :/

Closed 2016-05-13.

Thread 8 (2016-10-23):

Changed BOM and placement of parts

luftek, 2016-10-23:
Does recent change of BOM and placement affect "connector" position? With connector position I mean: both USB versions, DC socket, LEDs, u.fl conn
Thank you for support!

Dovydas-R, 2016-10-24:
USB connector, DC socket and LEDs positions are the same.
u.fl RF connector slightly changed their positions due to additional components.
Also there is additional u.fl connector (REF_CLK_OUT).

luftek, 2016-10-24:
Thank you for fast replay!

luftek, 2016-10-24:
Is there a way you make a photo of new revision? :)

luftek, 2016-11-01:
Is there a way you make a top side photo of new revision? :)

Dovydas-R, 2016-11-07:
Today we uploaded project files for new board version. Enjoy :)

Closed 2016-11-07.

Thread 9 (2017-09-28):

The LimeSDR board is broken?

wynter-wang, 2017-09-28:
Hi, I wanna run OAI eNB use the board. Then I run the process, it aborted(core dump)!  I checked it, shows:
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

and the leds(2 red and 2 yellow) beside USB port keep bright always! Who can tell me the reason and help me sovle the problem, Thanks a lot!

rjonaitis, 2017-09-29:
WestBridge name indicates the FX3 controller has not loaded firmware, check if the FX3 Boot jumper is in place. https://discourse.myriadrf.org/t/just-trying-to-get-started-having-no-luck/1127/13?u=ignasj

wynter-wang, 2017-09-30:
Thanks! I have modified it successfully!

Closed 2017-09-30.

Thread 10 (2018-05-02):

Lack of a mechanical drawing

viniciusmiguel, 2018-05-02:
Guys, please create a board mechanical drawing with the board and roles dimensions and distances.

MountainLogic, 2018-05-25:
from [https://discourse.myriadrf.org/t/limesdr-dimensions-and-case/298] the holes and dimensions are:

```
board size                  : 100 mm x 60 mm
board thickness             : 1.6 mm +/- 10 %
number of layers            : 12 (10 inner)

Drill files
	- LimeSDR_1v2.DRR -> Drill report detailing the tool assignments, hole sizes, hole count and tool travel.

Four 3mm diameter holes were drilled
 one hole at  3.85 mm,  3.85 mm
 one hole at 96.15 mm,  3.85 mm
 one hole at 96.15 mm, 56.15 mm
 one hole at  3.85 mm, 56.15 mm
```
Personally for a home built case with the old school "A" type USB connector version I set the holes USB side holes 20 mm in from the side of the case to allow for a recessed USB connector and the USB connector is just slightly recessed.

```
............................    _
.          |----|          .    |
.          |    |          .  20MM
.  |-------|    |-------|  .    |
.  |  *               * |  .    -
.  |                    |  .
.  |                    |  .
.  |                    |  .
.  |  *               * |  .
.  |--------------------|  .
.                          .
.                          .
............................

```

ztamosevicius, 2019-06-26:
PCB mechanical drawing files added in 1fa7cf584cd0e97e3f7b18e9752d91d87156ec3f commit.

Closed 2019-06-26.

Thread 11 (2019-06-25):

A/D and D/A Enob?

heitorPB, 2019-06-25:
A quick ctrl+f didn't gave me the information about the effective number of bits of the Digital<->Analog converters. Do you have this information somewhere?

ztamosevicius, 2019-06-26:
As it stated in LMS7002M datasheet, DAC/ADC ENOB is 9 bits.

Closed 2019-06-26.

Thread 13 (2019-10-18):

If the LimeSDR can switch to the USB Type-C interface?

GSCmax, 2019-10-18:
Hi, MyriadRF, this is Aaron.
Do you have any plans to upgrade the USB interface of LimeSDR?
USB Type-C port is now very common. It’s smaller, supports USB3.1 gen2 standard, and can provide faster transmission speed at the same time carry more current.
I think it's time to switch to the USB Type-C interface for LimeSDR.

hauserkristof, 2023-04-17:
Dear @GSCmax !

I'm currently working on a USB-A to USB-C flex pcb, to at least be able to use a better connector for the LimeSDR.

If you are interested I can send you the current design. After tested out I am going to upload it to GitHub for free.

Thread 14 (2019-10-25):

Possibly cooked LimeSDR-USB

wighthat, 2019-10-25:
Hi myriadrf,

I think I may have killed a Lime by failing to connect a fan while leaving it running. LimeQuickTest shows the board as failed. Can you confirm that the below output would indicate a dead board, please? Also, if there’s a better place to ask this kind of question can you please point me in the right direction?

Thanks

Mike

sbc002:~$ LimeQuickTest
[ TESTING STARTED ]
->Start time: Fri Oct 25 12:44:11 2019

->Device: LimeSDR-USB, media=USB 3.0, module=FX3, addr=1d50:6108, serial=0009072C00D52D1D
  Serial Number: 0009072C00D52D1D

[ Clock Network Test ]
->FX3 GPIF clock test
  Test results: 31171; 34927; 38683 - PASSED
->Si5351C test
  CLK0: 17554 / 17554 - PASSED
  CLK1: 17554 / 17554 - PASSED
  CLK2: 17554 / 17554 - PASSED
  CLK3: 17554 / 17554 - PASSED
  CLK4: 17554 / 17554 - PASSED
  CLK5: 17554 / 17554 - PASSED
  CLK6: 17554 / 17554 - PASSED
->ADF4002 Test
  Result: 10 - PASSED
->VCTCXO test
  Results : 5112924 (min); 5113070 (max) - PASSED
->Clock Network Test PASSED

[ FPGA EEPROM Test ]
->Read EEPROM
->Read data: 12 0C 06 12 0C 06 02
->FPGA EEPROM Test PASSED

[ LMS7002M Test ]
->Perform Registers Test
->External Reset line test
  Reg 0x20: Write value 0xFFFD, Read value 0xFFFD
  Reg 0x20: value after reset 0x0FFFF
->LMS7002M Test PASSED

[ RF Loopback Test ]
Note: The test should be run without anything connected to RF ports
->Configure LMS
->Run Tests (TX_2-> LNA_L):
SetFrequencySXR(800 MHz) - cannot deliver frequency
->Run Tests (TX_1 -> LNA_W):
SetFrequencySXR(1800 MHz) - cannot deliver frequency
->Run Tests (TX_2-> LNA_H):
SetFrequencySXR(2500 MHz) - cannot deliver frequency
->RF Loopback Test FAILED

=> Board tests FAILED <=

Elapsed time: 1.52 seconds

Jelly478558074, 2020-05-18:
LimeSDR USB，What is the name of the transmitting antenna?

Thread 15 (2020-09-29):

BoM lists incorrect jack?

akhepcat, 2020-09-29:
Was trying to figure out what external power supply to get, and looked in the BoM  for the power jack so I could double-check my measurements.

The BoM at https://github.com/myriadrf/LimeSDR-USB/blob/master/hardware/plug/1v4/Project%20Outputs%20for%20LimeSDR-USB_1v4_LMS031pad/BOM/LimeSDR-USB_1v4_BOMr7.xls  (  the -r4 version as well )

lists a  2.1x5.5mm  power jack  -  however  the mounting dimensions on it are much smaller than the plug it fits, so my guess is that somebody pasted the wrong information.

My device *appears*  to have  a  3.0x1.1mm  jack

Can this get corrected?

Also,  somebody should update the wiki with some guidance on the external power adapters so it's not so difficult to find.

Thanks

ztamosevicius, 2020-10-05:
Component was OK, just description was wrong. BOM files updated, thank you for spotting this.

akhepcat, 2020-10-05:
FWIW,  this adapter works fine with my Lime-USB: https://www.amazon.com/gp/product/B00Y7KOB8Q

Closed 2020-10-06.

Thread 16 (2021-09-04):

EEPROM data missing

arshaki, 2021-09-04:
Hi, there are two EEPROM chips on LimeSDR USB board. I wasn't able to find the data to program those, where can it be sourced? Thanks

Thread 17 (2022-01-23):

Android Support

kralsam, 2022-01-23:
How can I use the LimeSDR-USB with android tablet? Do you planned android driver? Because android tablets very powerful this days.

9600, 2022-01-24:
All LimeSDR hardware is supported by [Lime Suite](https://github.com/myriadrf/LimeSuite) and for any issues related to the driver, please raise these via its tracker, rather than here, which is for the hardware design.

ISTR some have built Lime Suite on Android, since the underlying O/S is Linux. There are no plans at present for any Android-specific features or packaging etc.

kralsam, 2022-01-24:
Thank you for your reply.

Closed 2022-01-24.

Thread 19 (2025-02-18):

Where can I get a document showing all the PCB parts as laid out on the board?

eabase, 2025-02-18:
Do you have PDF or other document showing what each component is called and where exactly it is placed on the PCB? It should be part of the design documents, but I'm not sure where they are and if the require a special app to read/open.

For example:

I don't see `MN18` being mentioned on the board!
How can I know what the other parts near T3. T5, T9 are?

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

9600, 2025-02-18:
https://github.com/myriadrf/LimeSDR-USB/blob/master/hardware/plug/1v4/Project%20Outputs%20for%20LimeSDR-USB_1v4_LMS031pad/LimeSDR-USB_1v4_PCB_Drawings.PDF

eabase, 2025-02-19:
Great! Tank you.

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

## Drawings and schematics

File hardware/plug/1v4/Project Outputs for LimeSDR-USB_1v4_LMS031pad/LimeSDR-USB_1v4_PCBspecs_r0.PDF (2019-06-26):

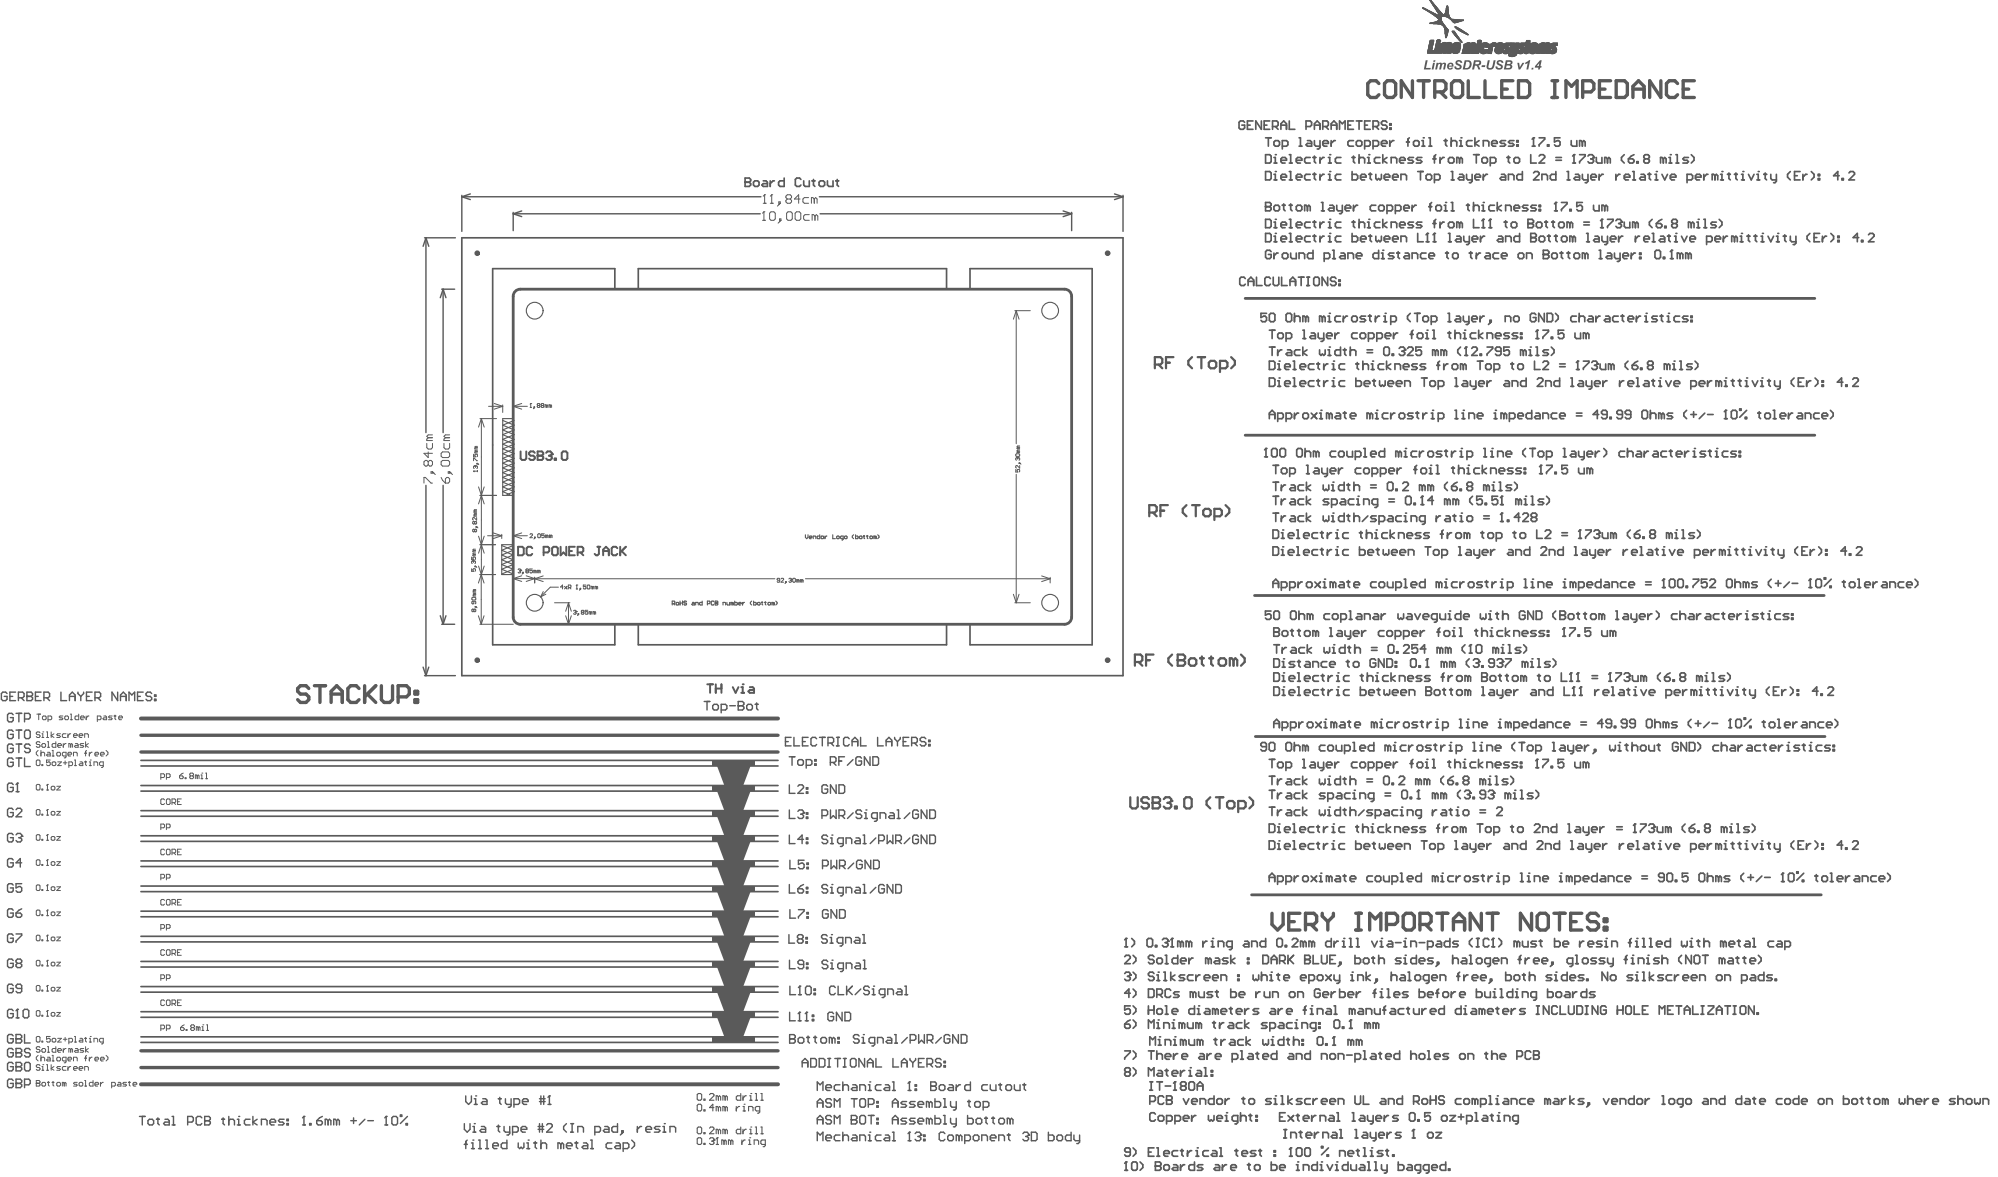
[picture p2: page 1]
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

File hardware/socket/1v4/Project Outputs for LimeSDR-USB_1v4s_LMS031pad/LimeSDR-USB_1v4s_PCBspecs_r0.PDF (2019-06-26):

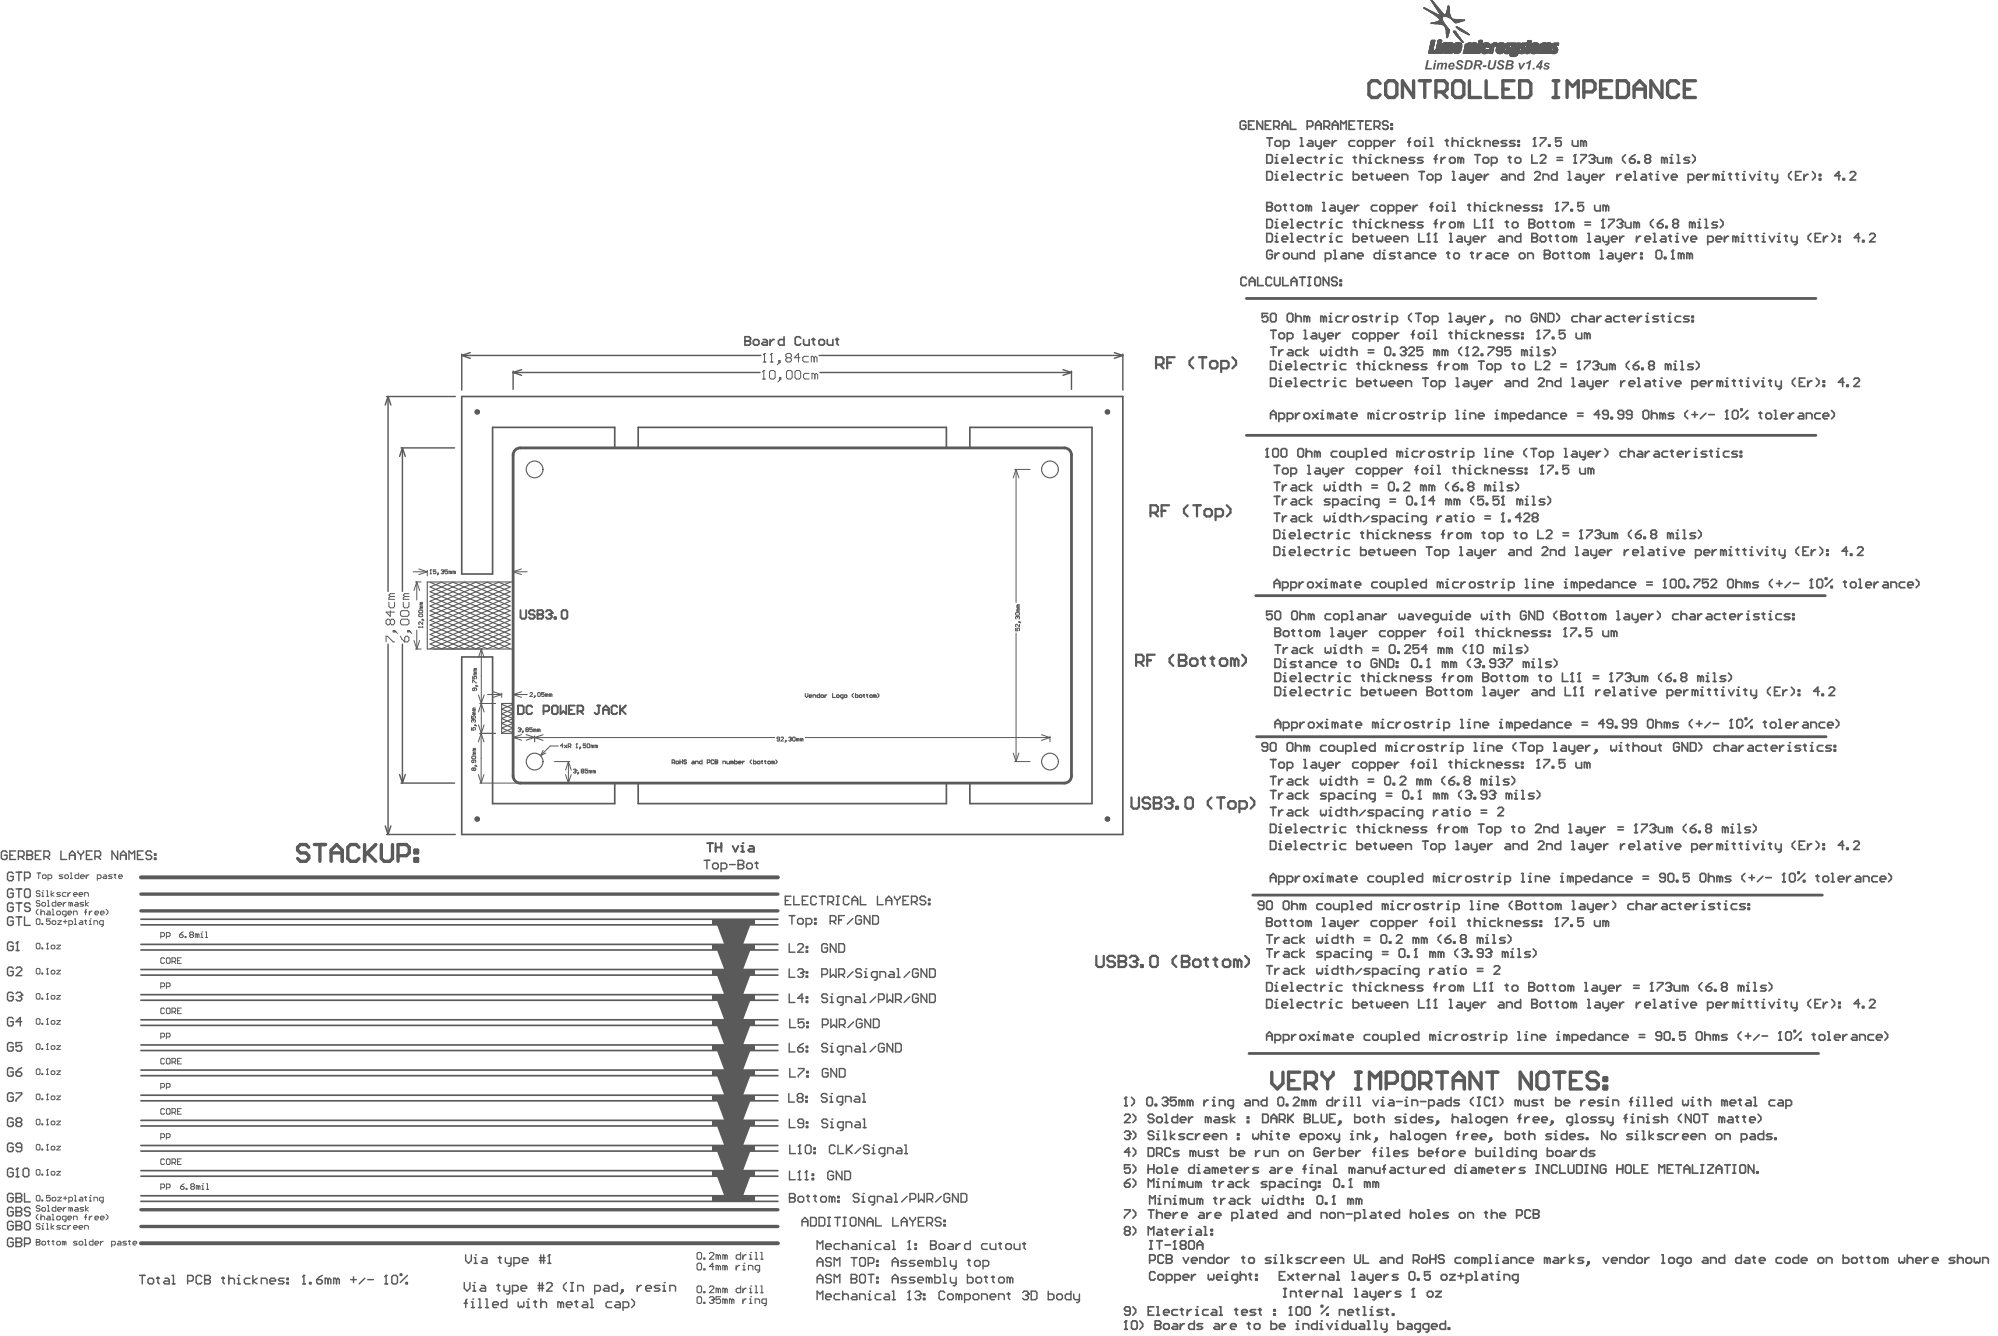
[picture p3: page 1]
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

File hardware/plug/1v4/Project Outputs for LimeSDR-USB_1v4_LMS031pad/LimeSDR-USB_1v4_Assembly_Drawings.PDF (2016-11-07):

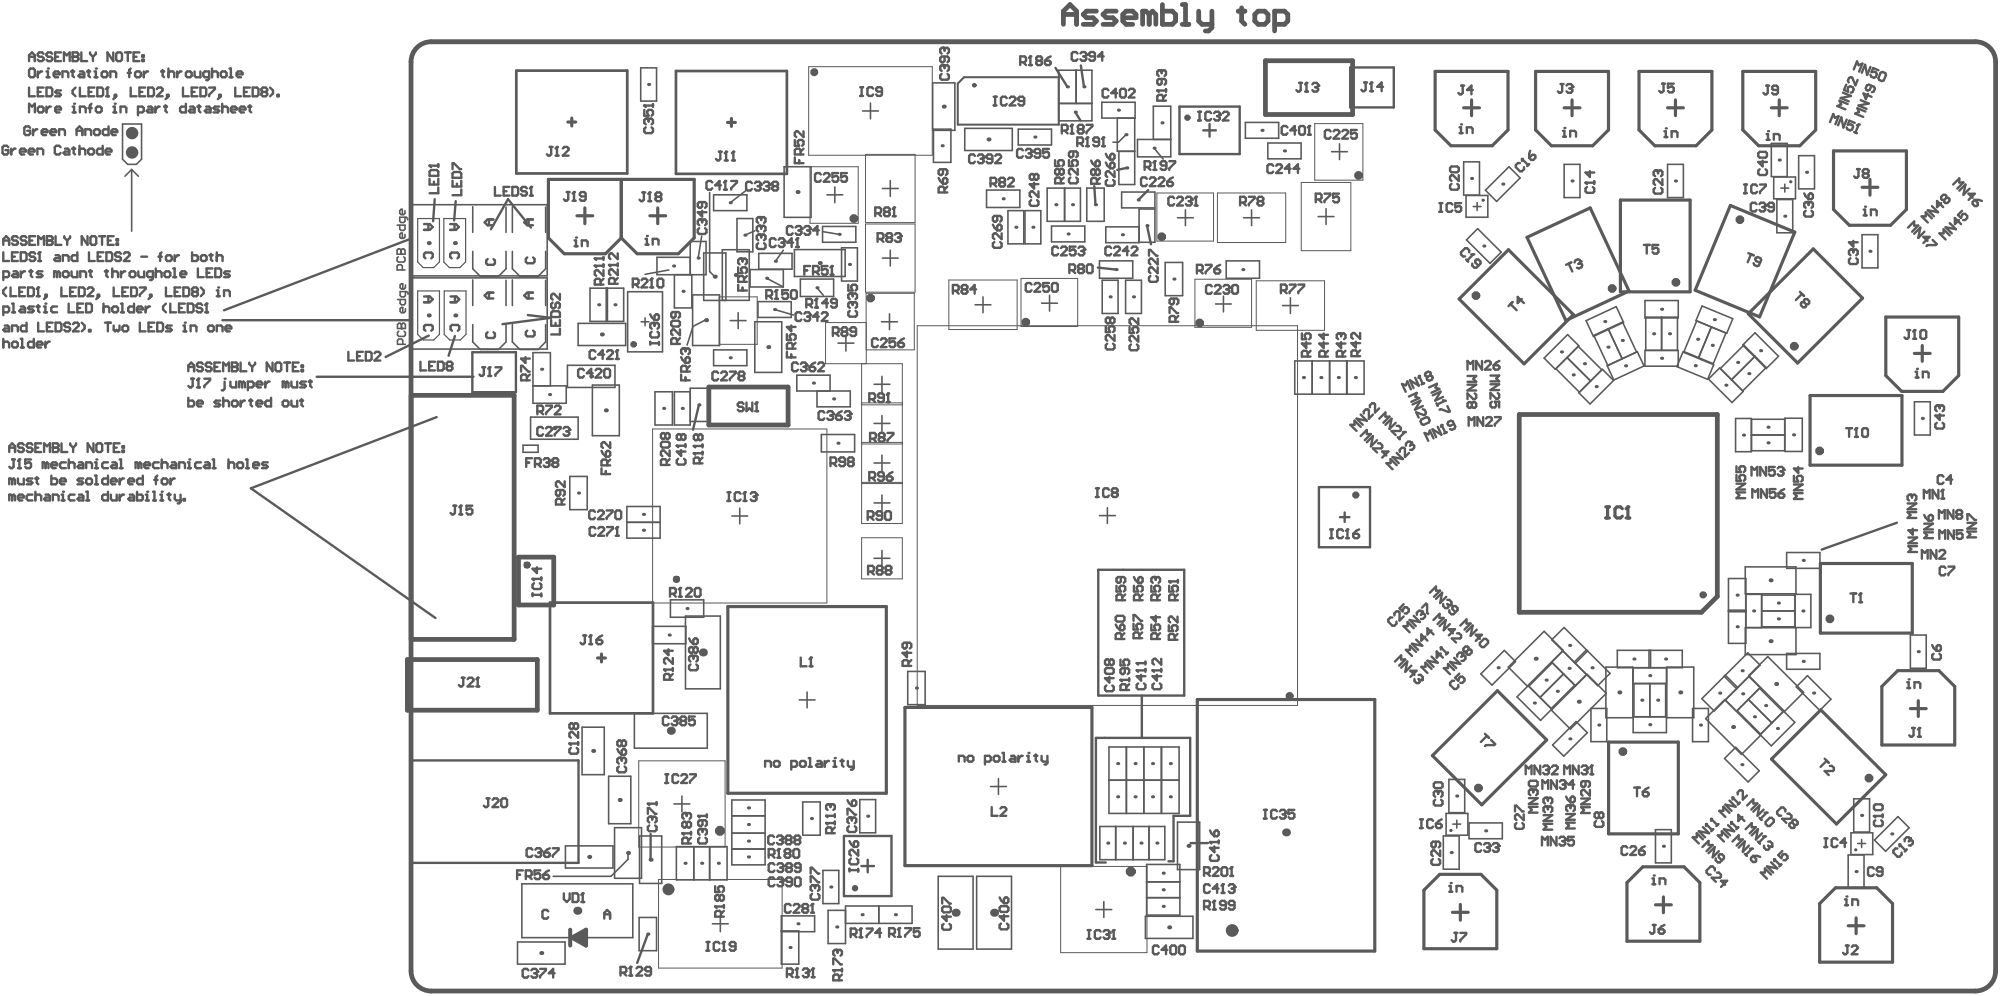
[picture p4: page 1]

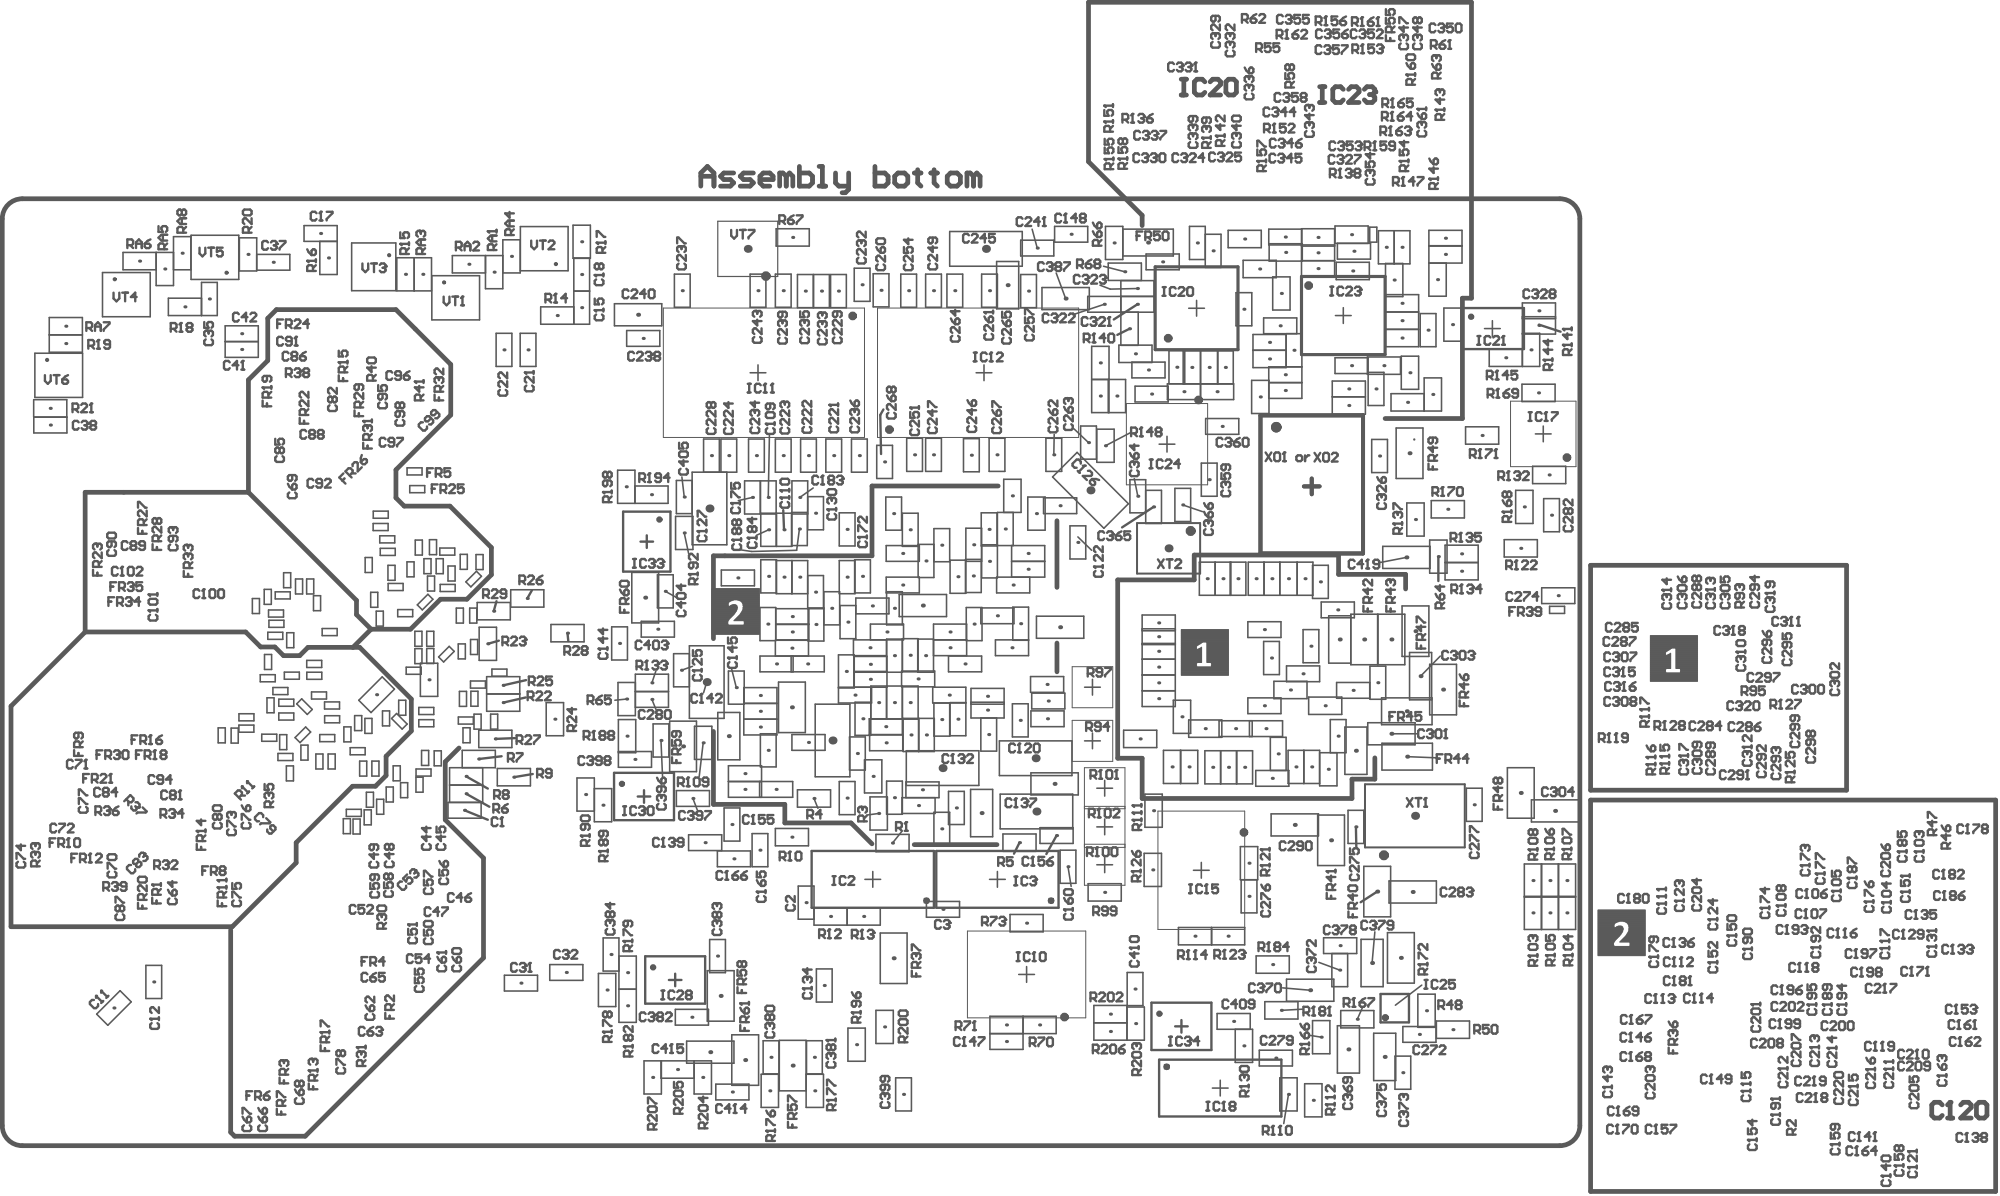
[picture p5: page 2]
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

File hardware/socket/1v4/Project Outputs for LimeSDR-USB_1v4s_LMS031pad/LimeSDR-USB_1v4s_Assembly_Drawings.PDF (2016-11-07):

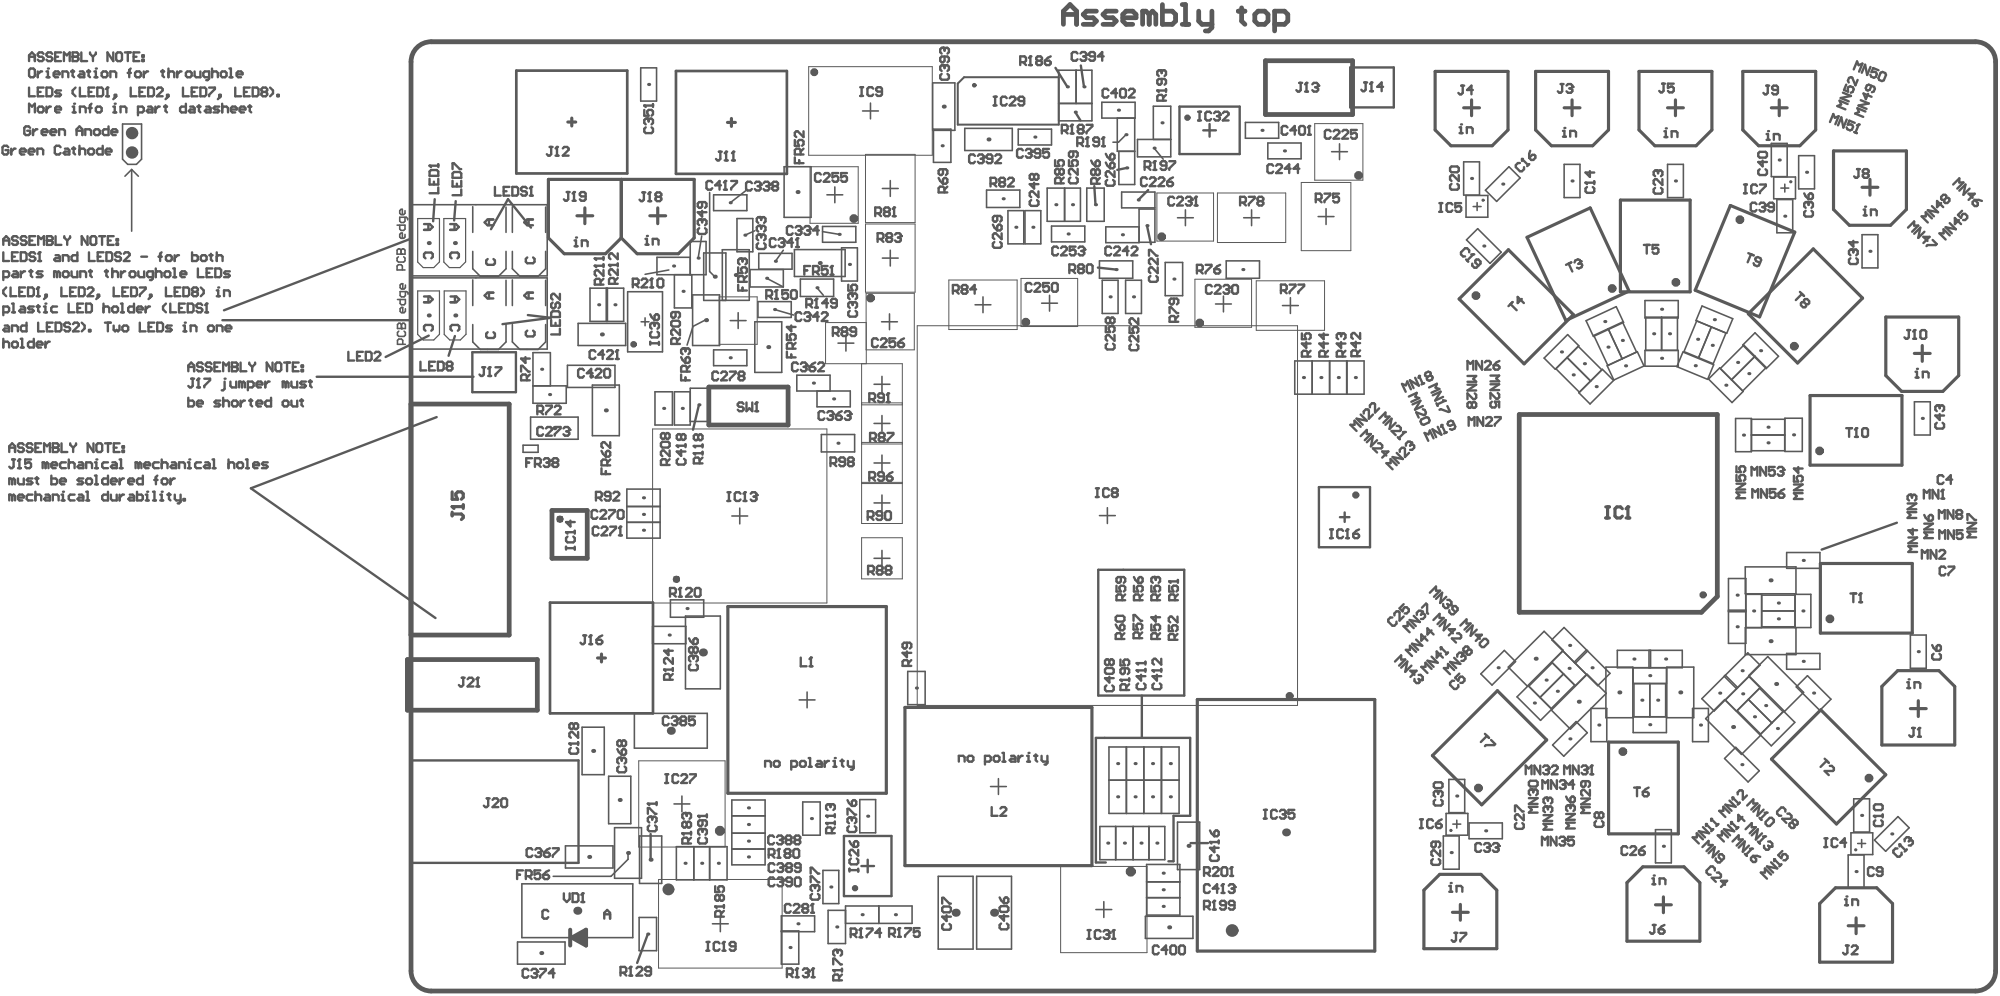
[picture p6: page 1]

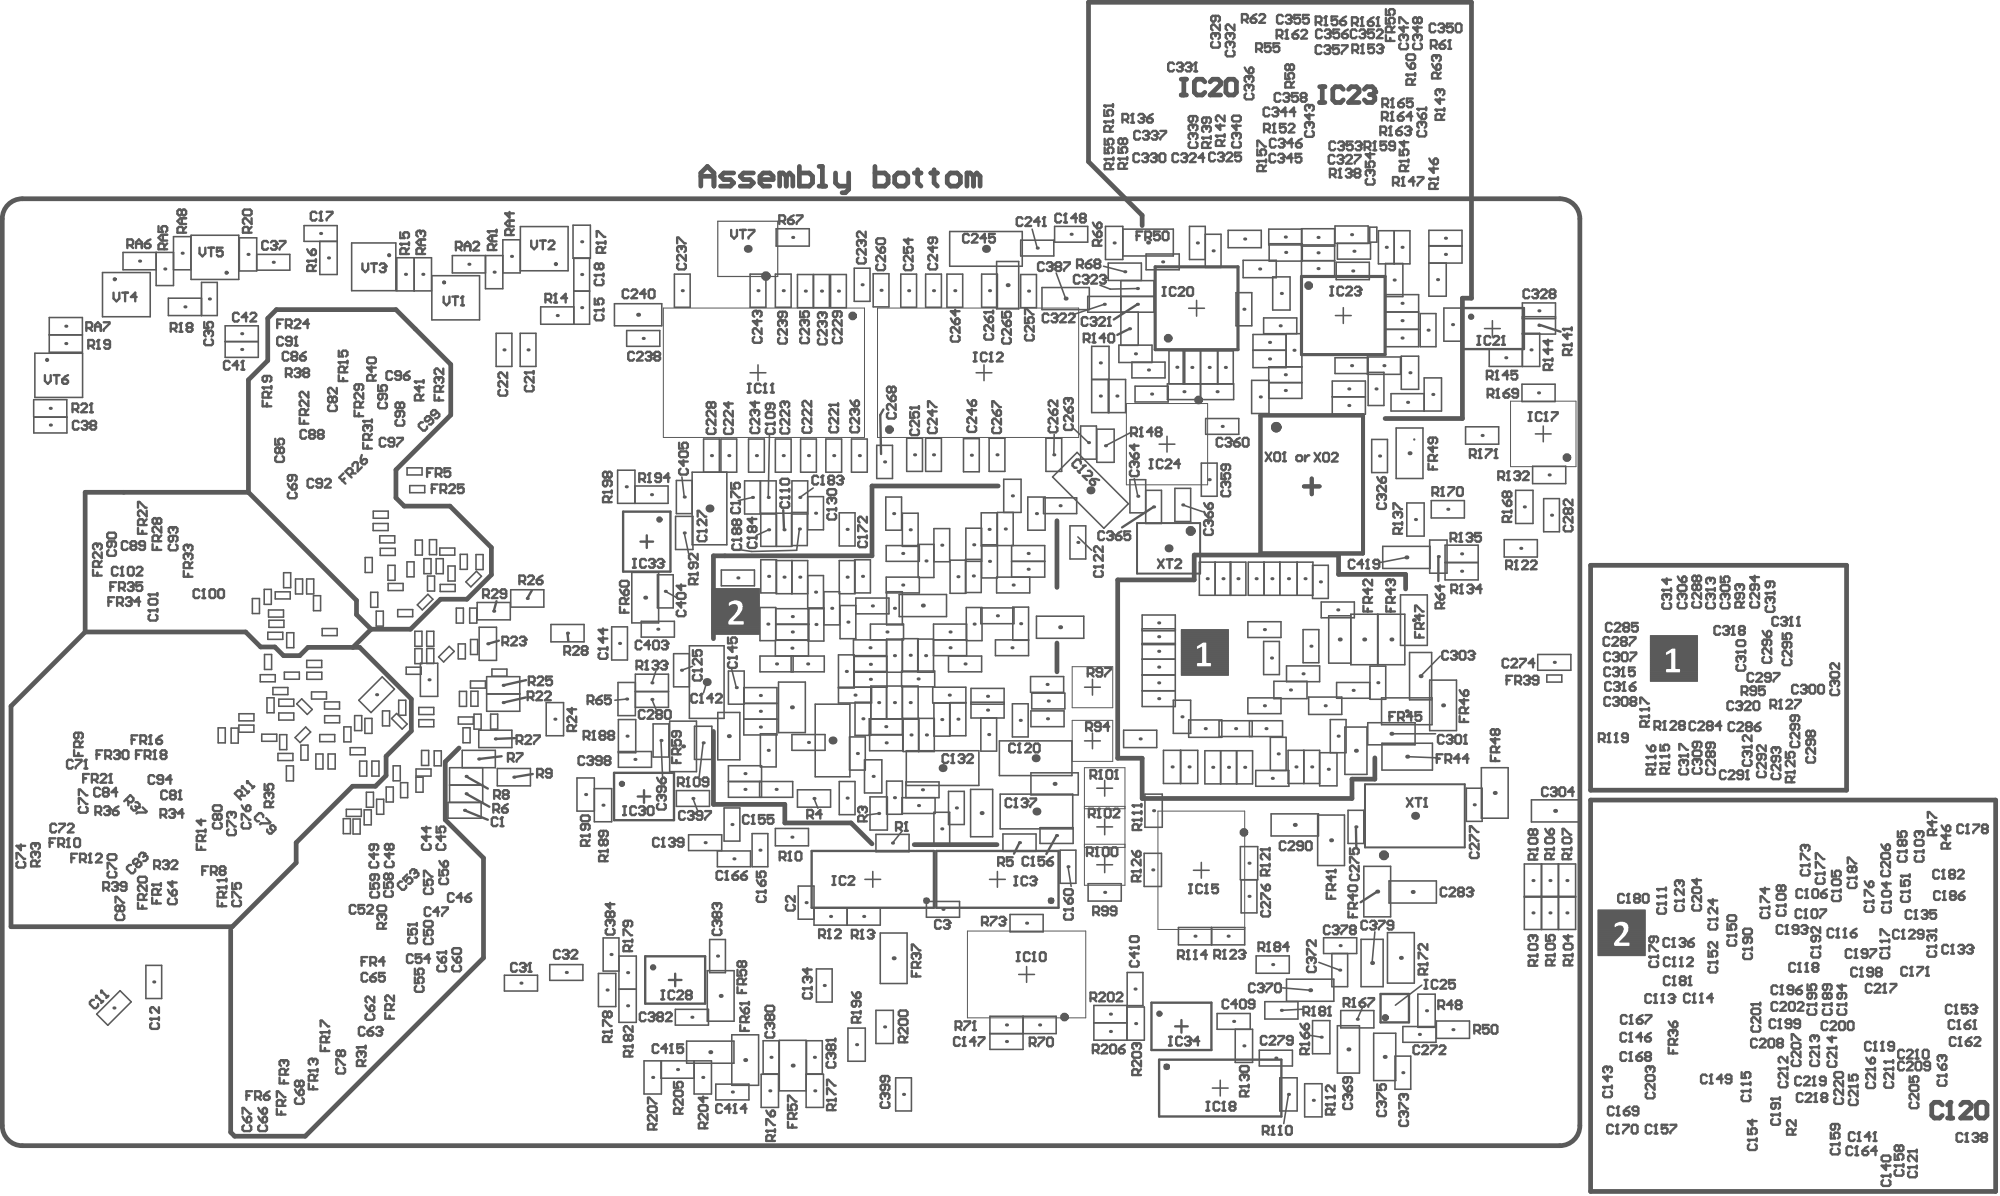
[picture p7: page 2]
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

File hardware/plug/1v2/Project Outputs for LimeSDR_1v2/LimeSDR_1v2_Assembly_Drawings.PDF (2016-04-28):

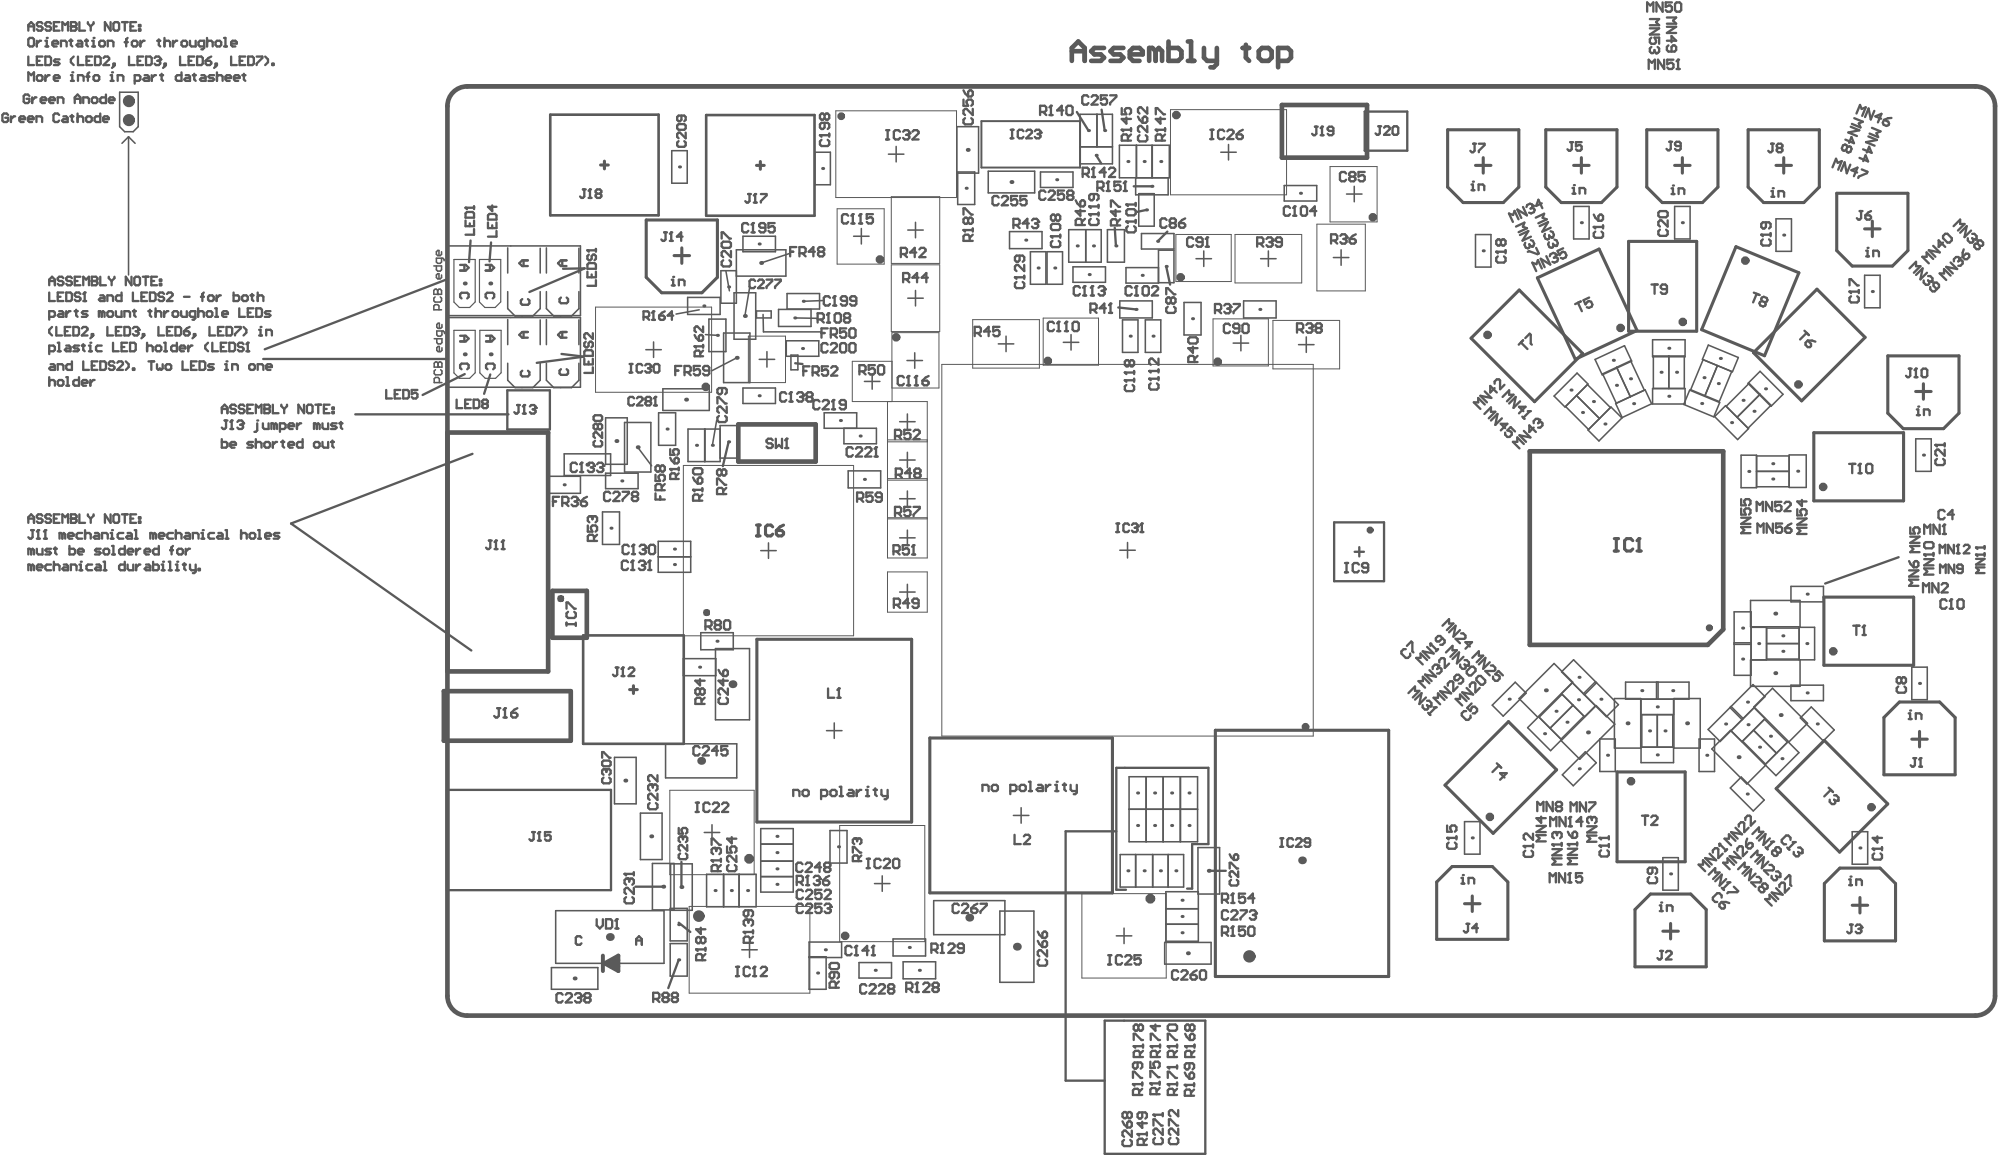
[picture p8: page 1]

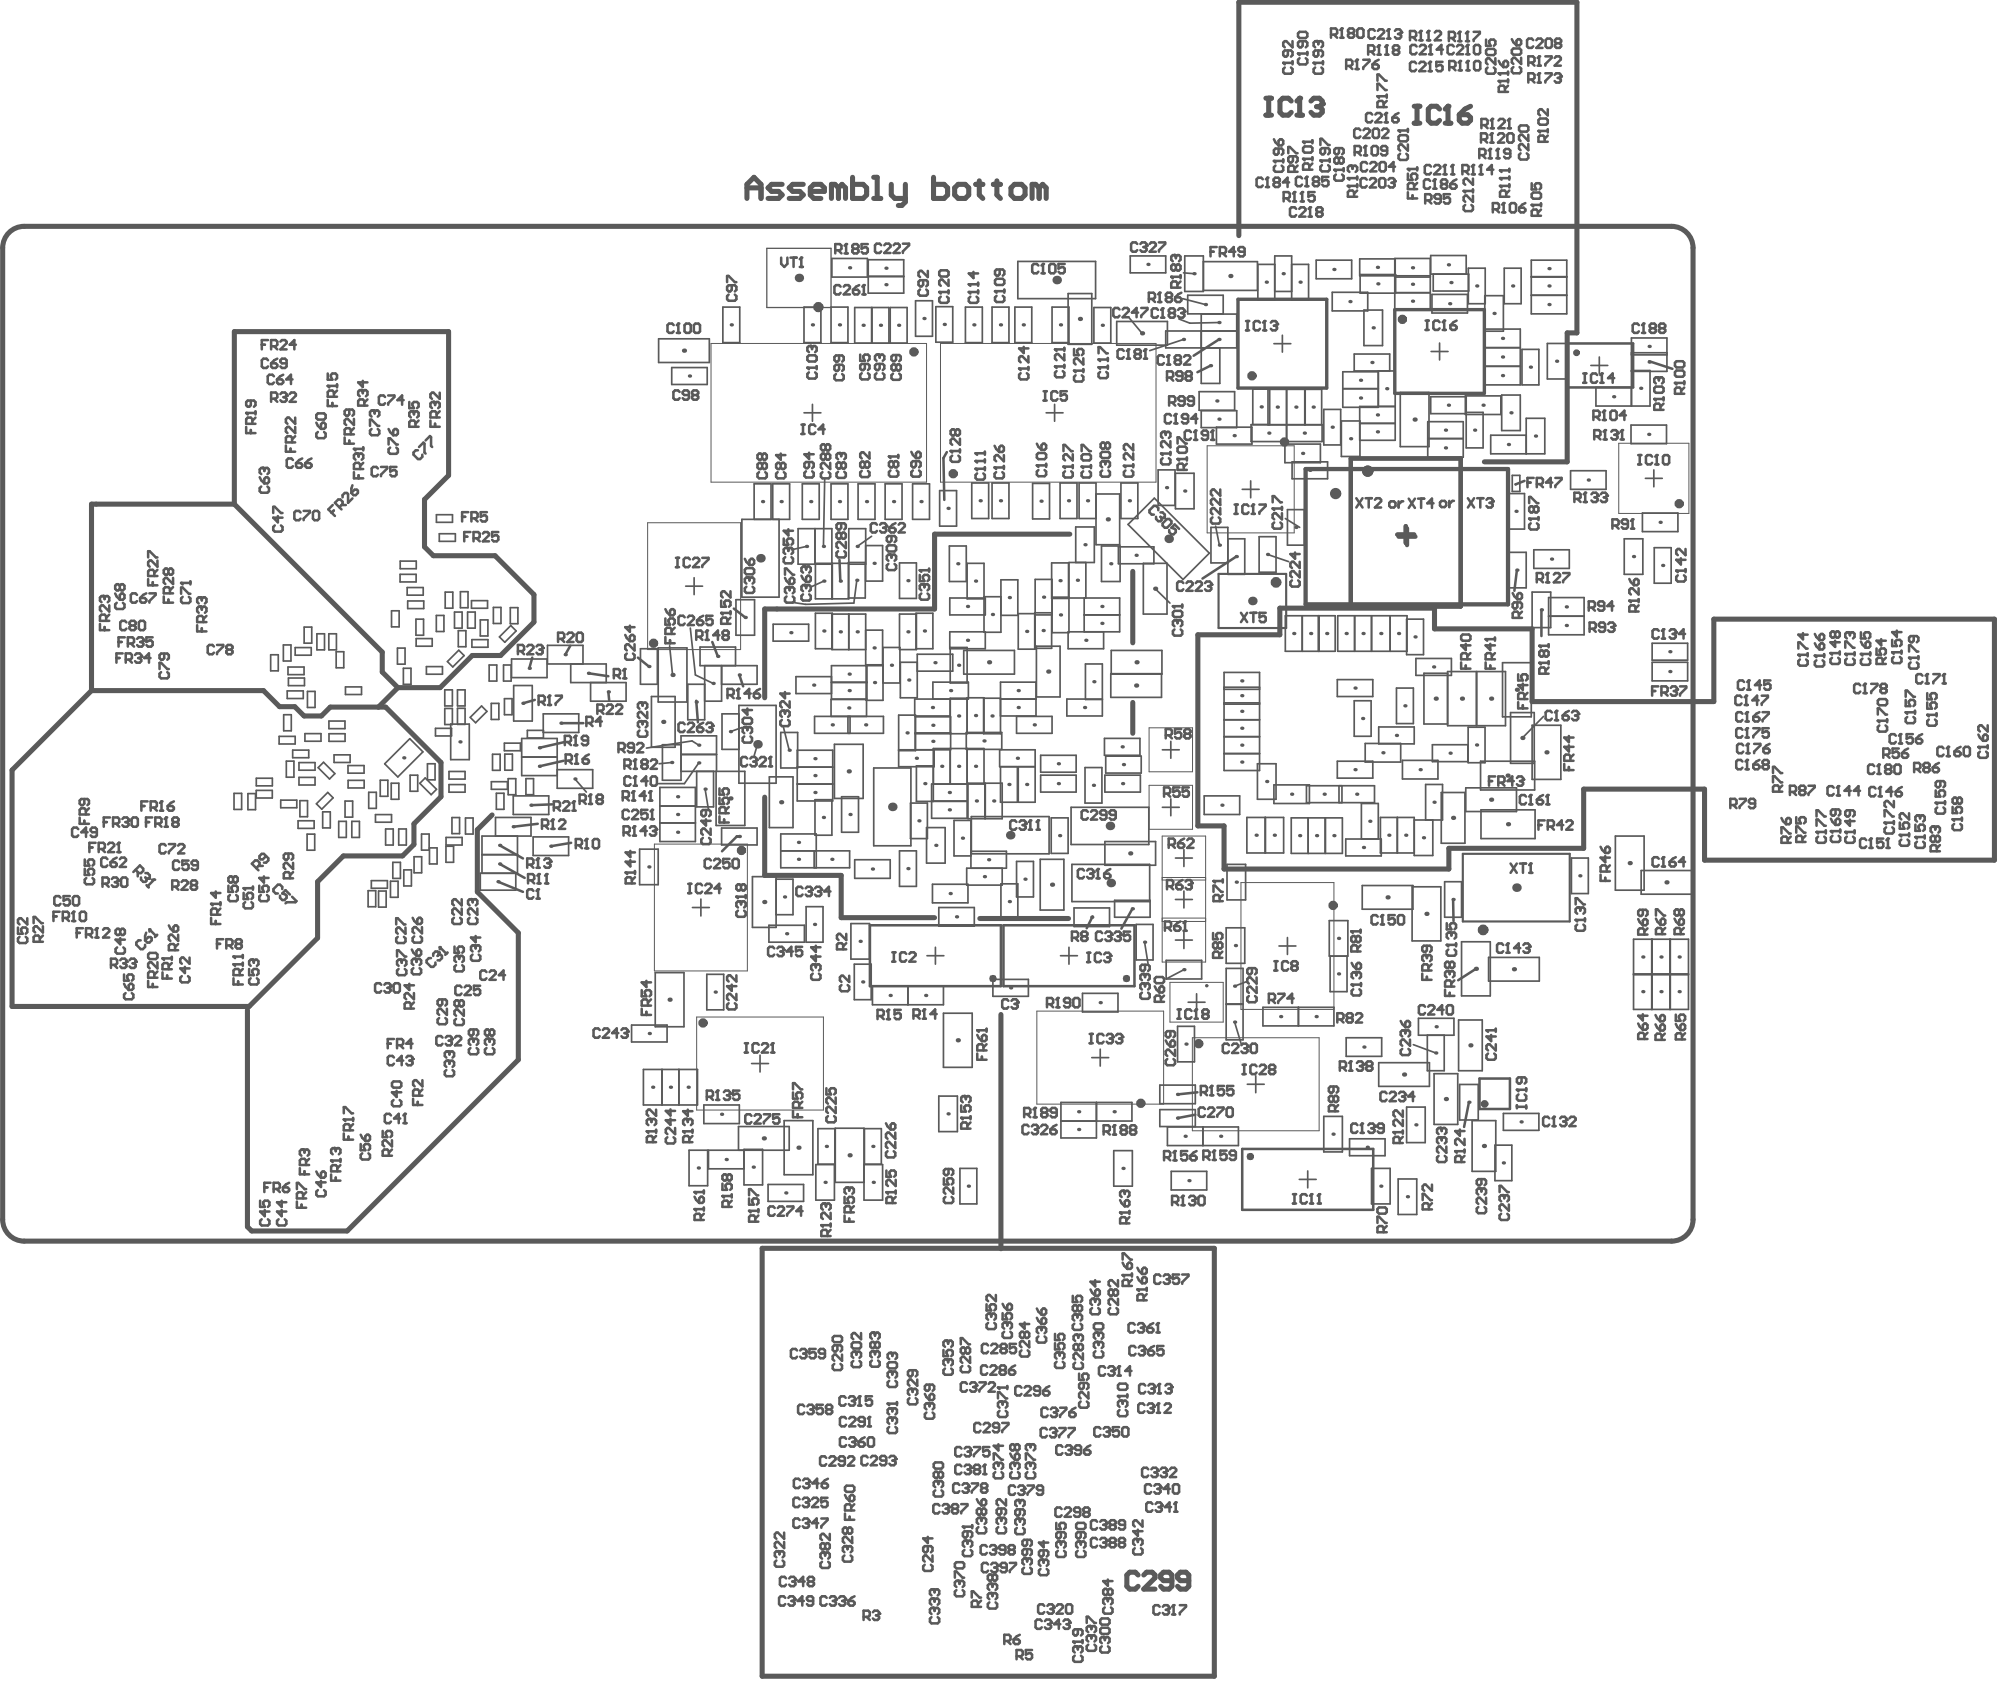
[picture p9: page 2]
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

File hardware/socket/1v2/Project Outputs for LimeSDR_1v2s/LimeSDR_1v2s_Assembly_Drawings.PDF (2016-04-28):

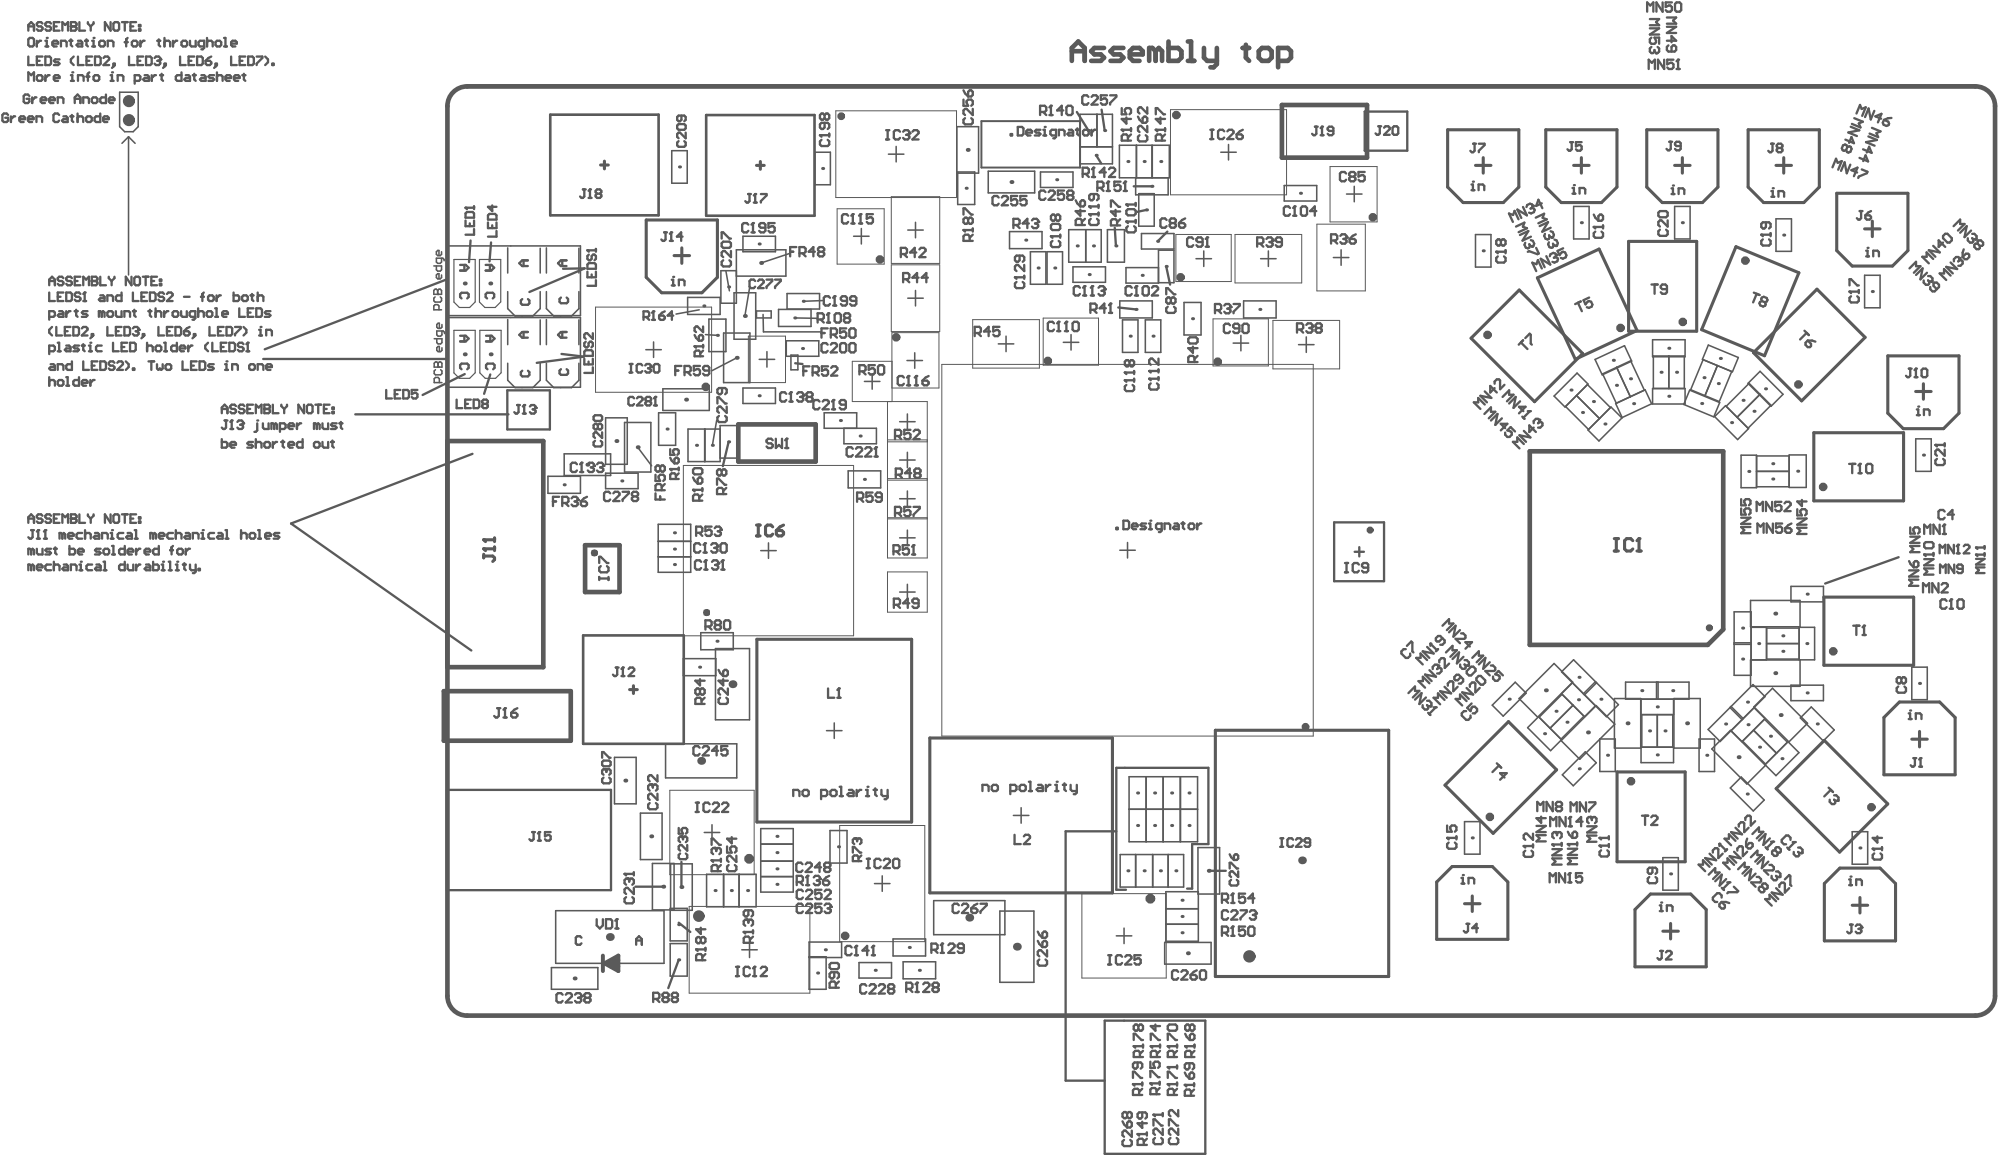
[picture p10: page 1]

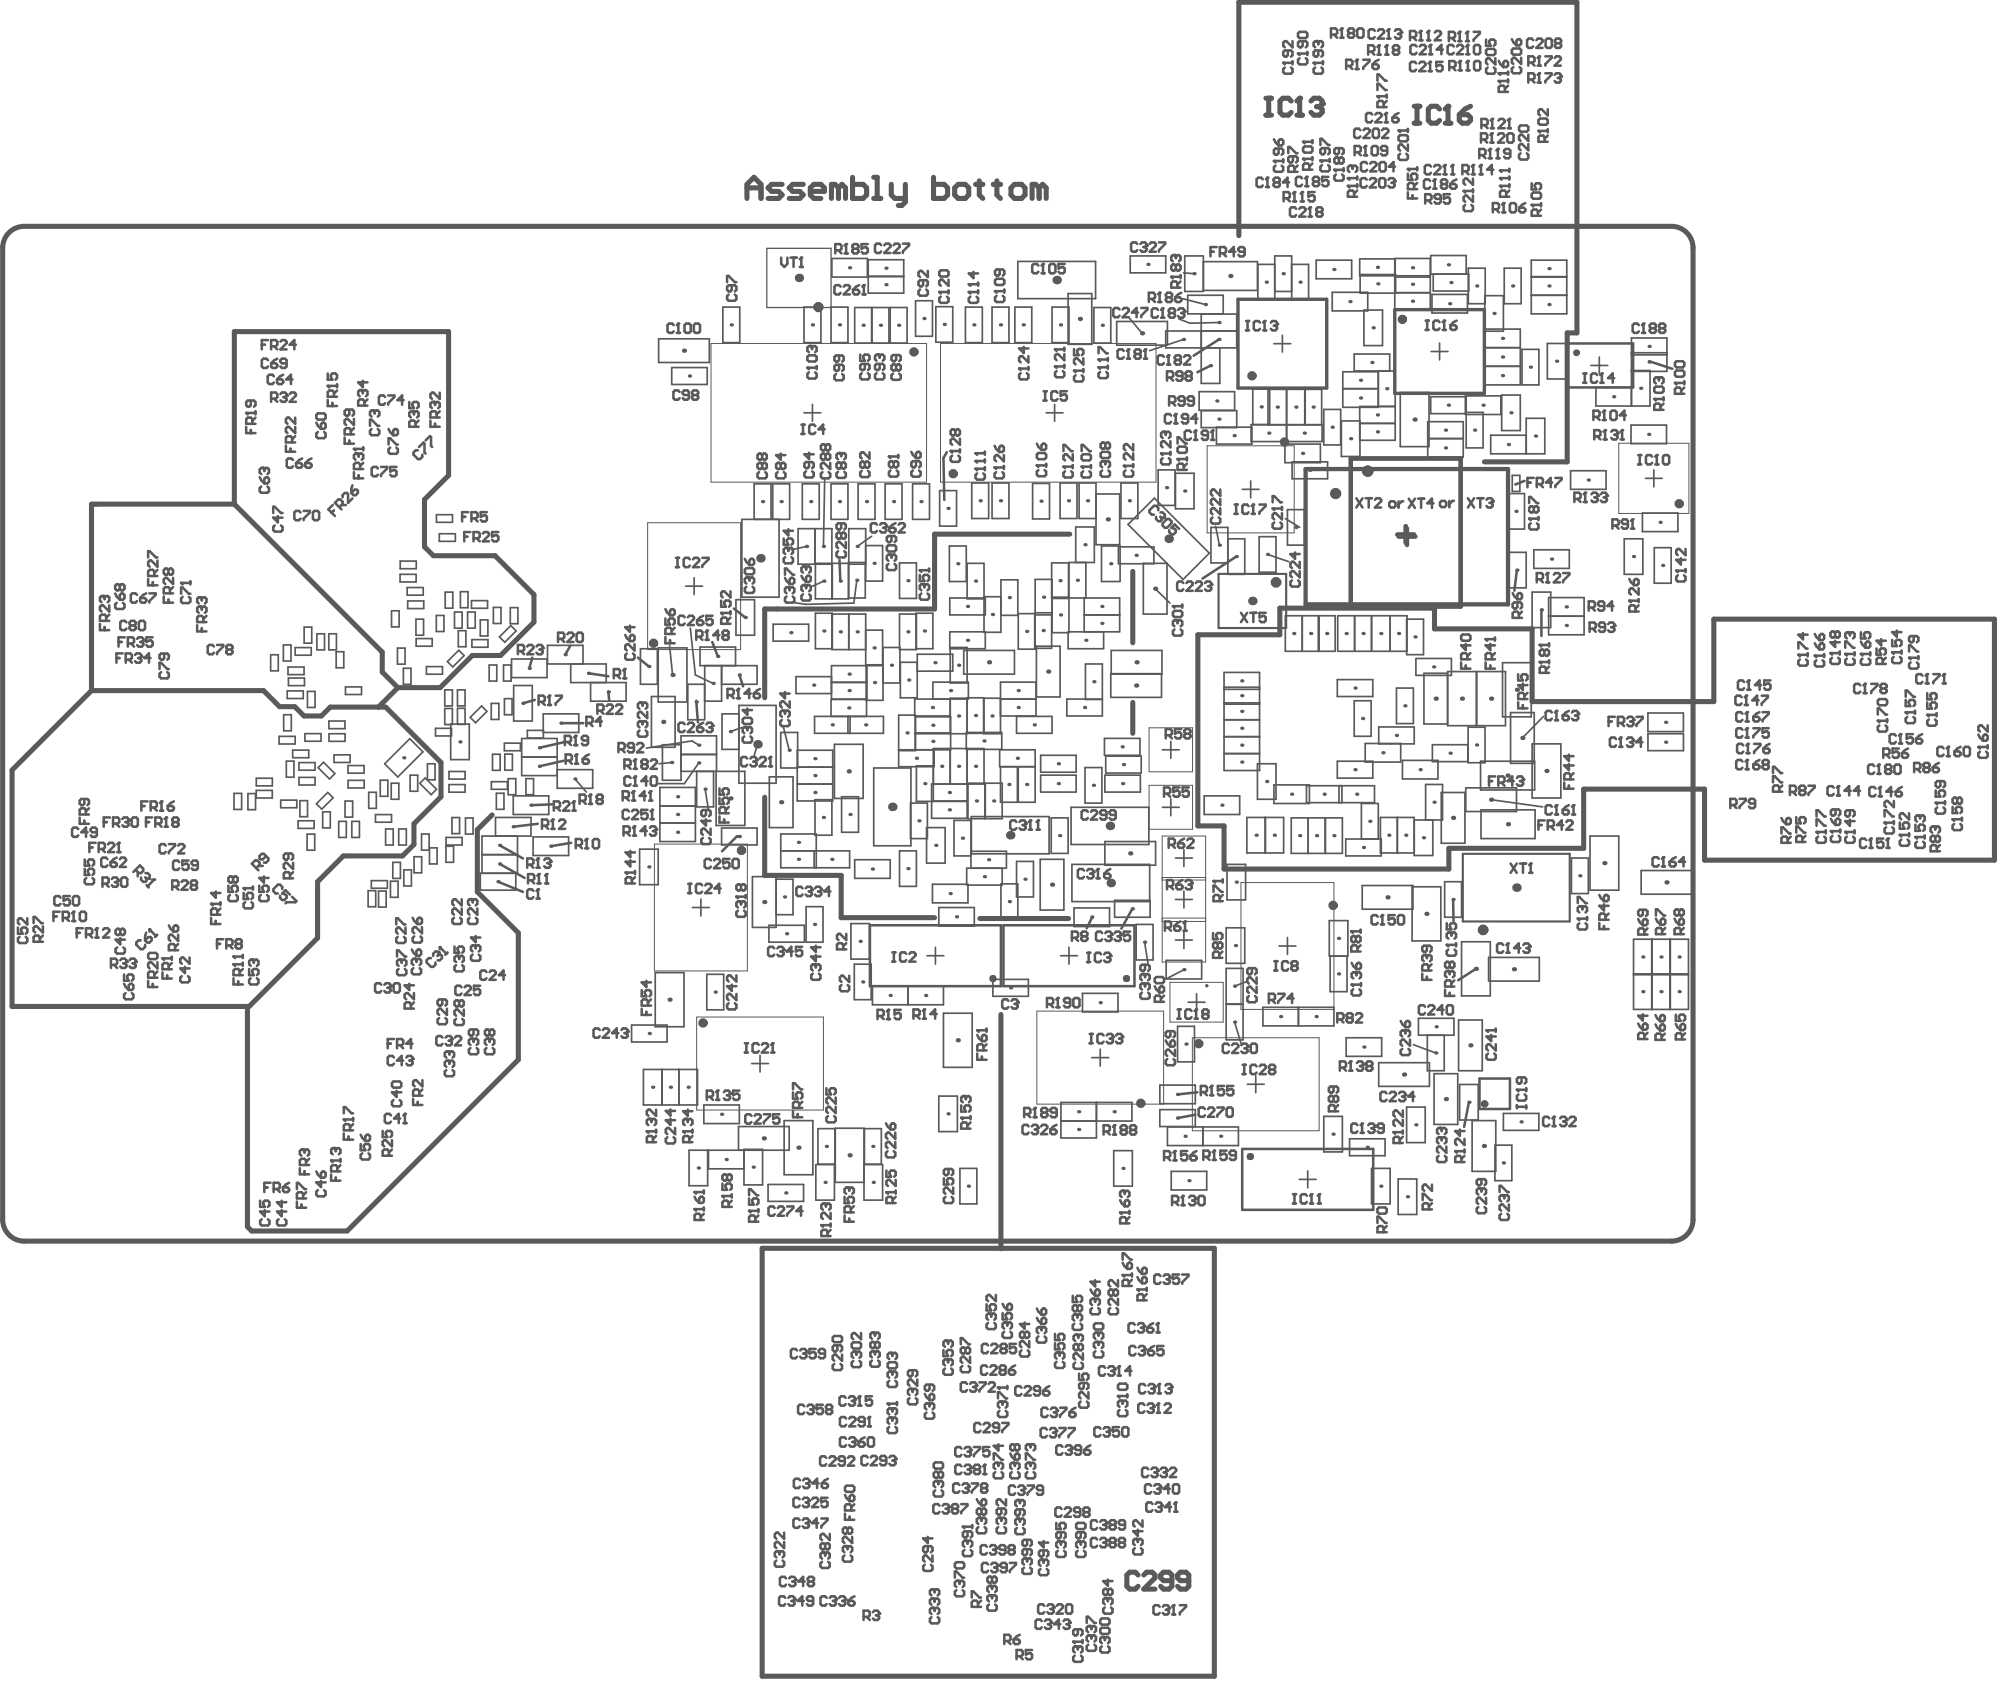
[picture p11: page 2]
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

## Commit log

2016-11-07 LimeSDR-USB 1v4 boards added.
    [01_BlockDiagram.SchDoc, 02_PowerDiagram.SchDoc, 03_ClockDiagram.SchDoc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]
2017-02-01 1v4 PCB projects updated.
    [01_BlockDiagram.SchDoc, 04_LMS7002M_Misc.SchDoc, 10_FPGA_misc.SchDoc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]
2017-02-06 Schematics for 1v4 boards added.
2017-07-19 Removed LimeSDR-USB_1v4s.pdf from socket
2017-07-19 Removed LimeSDR-USB_1v4s_schematic_r4.PDF from socket
2017-07-21 PCB libraries updated.
2019-06-26 PCB drawing files added.
2020-10-05 BOM files updated.
    [15_BoardPowerSupply.SchDoc, LimeSDR-USB_1v4_BOMr4.xls, LimeSDR-USB_1v4_BOMr7.xls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]
2020-11-11 ASCII design format files added.
    [01_BlockDiagram.SchDoc, ASCII_01_BlockDiagram.SchDoc, ASCII_02_PowerDiagram.SchDoc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]
